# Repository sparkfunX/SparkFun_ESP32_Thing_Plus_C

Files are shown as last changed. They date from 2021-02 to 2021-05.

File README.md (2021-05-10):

SparkFun ESP32 Thing Plus C
========================================

SparkFun ESP32 Thing Plus C (https://www.sparkfun.com/products/18018)

[*SparkFun ESP32 Thing Plus C (SPX-18018)*](https://www.sparkfun.com/products/18018)

The [SparkFun ESP32 Thing Plus C](https://www.sparkfun.com/products/18018) is a comprehensive development platform for [Espressif's ESP32](https://espressif.com/en/products/hardware/esp32/overview). Like the 8266 and ESP32 Thing, the ESP32 Thing Plus is a **WiFi**-compatible microcontroller with support for both **Bluetooth Classic** (i.e. SPP) and **Bluetooth low-energy** (i.e. BLE, BT4.0, Bluetooth Smart), a Qwiic connector, and 21 I/O pins. Add to that a rich set of peripherals ranging from capacitive touch sensors, Hall sensors, SD card interface, Ethernet, high-speed SPIs, UARTs, I2S and I<sup>2</sup>C.

We took all the good from the original [ESP32 Thing Plus](https://www.sparkfun.com/products/15663) and sprinkled on some more! USB C provides up to 2A, upgraded 16MB flash ESP32 WROOM module, CH340 USB to serial IC, an onboard fuel gauge IC will make sure you know your battery levels, and an onboard addressable LED is perfect for as a multi-status LED. Oh, and the new taller reset and boot buttons are *so* much easier to push!

We added a dedicator regulator to the Qwiic connector to enable software power control of the Qwiic bus - great for low power logging! There's even a microSD connector on the back!

The ESP32 Thing plus integrates a rich set of peripherals, ranging from capacitive touch sensors, Hall sensors, SD card interface, Ethernet, high-speed SPI, UART, I2S and I2C. Thanks to the onboard ESP32 WROOM module, the SparkFun Thing Plus features 16MB of flash memory, 520kB of internal SRAM, an integrated 802.11 BGN WiFi transceiver and dual-mode Bluetooth capabilities, and a JST connector to plug in a LiPo battery.

For programming, select the 'ESP32 Dev Module'. This will get you direct pin to pin access to each of the WROOM's pins.

Repository Contents
-------------------

* **/Hardware** - Eagle design files (.brd, .sch)
* **/Firmware** - Example sketches demostrating extra peripherals

License Information
-------------------

This product is _**open source**_! 

Please review the LICENSE.md file for license information. 

If you have any questions or concerns on licensing, please contact technical support on our [SparkFun forums](https://forum.sparkfun.com/viewforum.php?f=152).

Distributed as-is; no warranty is given.

- Your friends at SparkFun.

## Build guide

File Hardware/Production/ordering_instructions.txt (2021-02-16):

panel size, 131x139mm
PCB thickness, 1.6mm
number of layers, 2
soldermask color, Black
silkscreen color, White
oz copper, 1oz
finish, HASL lead free
stencils, none
pcs per panel, 10
min trace width, 0.1270mm / 0.0050in
min drill size, 0.3048mm / 0.0120in

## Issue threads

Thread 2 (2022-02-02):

Add pullup to SD SDO

nseidle, 2022-02-02:
Intermittent issues with different SD cards fixed with a 100k pullup.

nseidle, 2022-02-02:
Reported issues with built-in ESP32 SD library. May behave differently with sdFat.

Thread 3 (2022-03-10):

QWIIC Twist and Quad Relay not recognized - Updated

jpecor, 2022-03-10:
I'm trying to use the Thing Plus C with a QWIIC Twist, and it does not recognize the device.  I have the Twist working with an RPi and Python library, so I know it functions.

I also tried the I2C scanner code from this repo, and the Twist is not seen on the bus.

Has the QWIIC interface been verified on this device?  Or is there something I should be doing differently?

jpecor, 2022-03-10:
I have the same issue with the QWIIC Quad Relay, so it's not just isolated to the Twist.

jpecor, 2022-03-10:
Yes, there is power to the Twist.  In fact, I ran the I2C scanner code, and it blinks the Twist LED, but there's no hit when it scans the addresses.

I haven't added other QWIIC boards to the chain to see if they are detected, yet.  I'll try that next.

jpecor, 2022-03-10:
Just tried with a QWIIC 9DoF IMU and PIR.  Same result.
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

PaulZC, 2022-03-10:
Hi Jason,

Which version of ESP32 do you have installed? And do you have the ESP32 Dev Module selected?

Qwiic / Wire is working fine for me...

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

Best wishes,
Paul

jpecor, 2022-03-10:
SHAZAM!!   I was not!  I was using the Adafruit ESP32 Feather based on the [instructions for the ESP32 Thing Plus.](https://learn.sparkfun.com/tutorials/esp32-thing-plus-hookup-guide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)

Changing to the ESP32 Dev Module seems to be the ticket.  Or, at least, I see the devices with the scanner code.

Now on to the intended application. If that works, I'll close this issue.

Thanks for the help!

jpecor, 2022-03-10:
That worked.  Thanks again!

jpecor, 2022-03-11:
I am reopening this issue because I've run into a new wrinkle.

Here's the situation:

- After switching the board to use the ESP32 Dev Module, the I2C Scanner sketch started working
- I switched back to my project setup, which is a Quad Relay and Twist, and it was working for those, as well.
- Then, we soldered header pins to the ESP32 C
- Post header attachment, I could no longer control the Twist/Relay - it doesn't see them there
- Additionally, if I have nothing connected to the QWIIC connector, the scanner tells me it's finding a device at 0x36

So, something changed post-header attachment.

Those through hole vias are *very* close to the ESP32 module CVs, and our concern was a possible solder bridge.  Everything looks very clean under the microscope.

Is it possible the proximity of the ESP32 module to the vias allowed some of the solder to flow under a CV and create an open on one of the module I/O?

I can still program the device, so it's not flat-out broken.  But the I2C bus is not working correctly.

Any thoughts?

Thanks!
Jason

PaulZC, 2022-03-11:
Hi Jason,

The device at 0x36 is the MAX17048 battery fuel gauge. That suggests the I2C bus is still working correctly.

Are you still connecting via the 4-Pin Qwiic connector? Maybe try connecting via the SCL/SDA header pins instead?

Best wishes,
Paul

jpecor, 2022-03-11:
Yes, I'm using the QWIIC connector.  I'll try the header pins next.

Thanks for the Intel on the battery gauge.  Good to know!

jpecor, 2022-03-11:
Direct connection to SDA/SCL works. Hmmm....

Thanks @PaulZC !

nseidle, 2022-03-14:
Sorry you're having so much trouble. Sounds like a bad Qwiic cable or bad connection. Continuity test the cable to see if it's bad. Also have a good look at the pins inside the Qwiic connector. It's rare but I've had an end pin bend sideways a few times.

Closing since it's not a hardware issue with the ESP32 Thing Plus C. Feel free to open more issues if you come across them.

Closed 2022-03-14.

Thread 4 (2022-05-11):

Digital write to pin 18

Rubeanie, 2022-05-11:
I am unable to write to digital pin 18 (sck)?
I am just trying as you would with any other pin, nothing fancy. Every other pin I'm using work.

PaulZC, 2022-05-11:
Hello Ruben (@Rubeanie ),

The Thing Plus C is intentionally connected up differently to our other ESP32 Thing Plus boards - to provide access to all of the I/O pins. For the Thing Plus C we recommend installing Espressif's ESP32 board package and then selecting the _ESP32 Dev Module_ as the board. Once you have done that, SCK is digital pin 18 - not 10.

Quick summary:
* Follow [Espressif's instructions ](https://docs.espressif.com/projects/arduino-esp32/en/latest/installing.html) to install the ESP32 board package
  * Add this line to your _Additional Board Manager URLs_ :
  * https://raw.githubusercontent.com/espressif/arduino-esp32/gh-pages/package_esp32_index.json
  * (If you have more than one additional URL, separate them with commas)
* Once you have the ESP32 boards installed, from the _Tools_ menu, select _Board_ \ _ESP32 Arduino_ \ _ESP32 Dev Module_
  * (Do not select any of the other Dev Modules, or any of the SparkFun ESP32 boards)

For more information on which pin is which, please refer to [the schematic](https://cdn.sparkfun.com/assets/b/5/1/0/9/SparkFun_ESP32_Thing_Plus_C.pdf):

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

Best wishes,
Paul

Rubeanie, 2022-05-12:
Sorry, that was a typo, I meant pin 18. I need to set it to 3v3 to run a stepper driver. All the other pins I'm using for it work aside from pin 18.

Rubeanie, 2022-05-13:
I set pin 18 to high, then checked all the pins with a multimeter. I found that pin 32 was high when trying to set pin 18. After finding this out, I tried setting pin 32 to high, and then pin 18 went high.
I don't think it's an issue with every board but for some reason, my pin 18 and 32 are swapped, it works fine now that I know this, it's just confusing.

PaulZC, 2022-05-13:
Hi Ruben (@Rubeanie ),

Wow. How bizarre! I _think_ the only way that can happen is if the variant pins_arduino.h has been changed, or if you have the wrong board selected? Please check one last time that you have the latest ESP32 boards (v2.0.3) installed and that you have the _**ESP32 Dev Module**_ selected.

I'm going to close this issue, but please re-open it if you need more help with this.

Very best wishes,
Paul

Closed 2022-05-13.

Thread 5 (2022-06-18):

SDIO functionality made impossible

idea--list, 2022-06-18:
Hooked up this board with an external uSD slot wired up for SDIO 4-bit mode as i was looking for high data rates.
On the ESP32 chip GPIO_2 and GPIO_7 have SD_DATA0 functionality.
On this board the RGB LED occupies GPIO_2. GPIO_7 is not broken out.
This is really unfortunate as this way we can not interface an SD card neither in SDIO 1-bit nor in SDIO 4-bit modes.

If the RGB LED would occupy either an SD_DATA1 or SD_DATA2 capable pin, we could use at least SDIO 1-bit mode (which needs SD_DATA0 and SD_DATA3)
Best would be however to keep all SDIO relevant pins broken out on the header.

PaulZC, 2022-06-21:
Hi Peter (@idea--list ),

This is a good suggestion - thank you. We will make note of this for future boards and revisions.

Forgive me for asking, but have you tried to use SDIO on this board? Yes, the RGB LED is connected to GPIO_2 but the LED is just an input. I suspect that SDIO may still work? OK, yes, the LED will be very confused and may show very random colors. But does it actually stop SDIO from working?

Many thanks,
Paul

idea--list, 2022-07-23:
@PaulZC
Was away for some time...

Just tried to test it once more.
Wrote some code in ESP-IDF to try different modes of SD-card connection.
This particular board uses the VSPI pins of the MCU to connect to the on-board uSD-slot, which is working as expected.
Using the HSPI pins i also connected an external uSD slot, which is also working fine in SPI mode. Yes, the RGB LED is occupying GPIO2 but the test point centrally from pin 4 seems to be the connection to the RGB LED. So while the external uSD slot is active, the RGB LED lights up in different colors.

However as soon as i switch to SDIO1 or SDIO4 modes i get this message in ESP-IDF:
E (6049) sdmmc_common: sdmmc_init_ocr: send_op_cond (1) returned 0x107
E (6050) vfs_fat_sdmmc: sdmmc_card_init failed (0x107).
[  6053][E][SD_MMC.cpp:138] begin(): Failed to initialize the card (0x107). Make sure SD card lines have pull-up resistors in place.

On my Wemos Lolin D32 and Adafruit Feather ESP32S3 boards even SDIO1 and SDIO4 modes work as expected, so i guess the RGB LED affects the pullups-check in ESP-IDF.

This issue became less relevant for me since the [Thing Plus Dual-Port Logging Shield](https://www.sparkfun.com/products/19217) has been released. Will absolutely need to buy some!

PaulZC, 2022-07-23:
Hi Peter (@idea--list ),

Many thanks for the feedback - we really appreciate it.

We have two new boards in the pipeline: a tweaked version of this Thing Plus C; and a new ESP32-WROOM-based board with microSD. The first won't support full SDIO as the changes would have been too drastic. For the second, I've designed in 4-bit SDIO from the start. It has the required pull-ups, plus isolation on the strapping pins so the pull-ups (which could be pull-downs if the microSD is deenergized!) won't interfere with the boot process.

Let me know how you get on with the dual-port shield. That was a fun design to work on! The first batch sold out really quickly. It should be back in stock soon.

Very best wishes,
Paul

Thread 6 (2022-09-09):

ESP32 GPIO peripheral interrupts issue - manifests as WiFi / power issue

idea--list, 2022-09-09:
Recently i added WiFi functionality to my project and ever since then i am facing reliability issues.

The program logic (written in ESP-IDF) does collect sensor data and records it to a uSD card using the on-board slot. I also slice up the files into 1 minute long units. Once the file of the following minute is created and recorded to, i wait 10 seconds before transferring the previous file over wifi. The wifi transaction takes only 2-8 seconds each minute. The code runs without any issues while powered from USB cable, no matter how many days the session takes. I am also using the auto light sleep feature of ESP-IDF to keep the consumption as low as possible.

However as soon as i power the board from a single 18650 battery, the program stops running between the 50th and 60th minute and on the server side i regularly find the last file smaller then on the SD card, meaning the ESP32 stopped working right during transmission of the previous file (actually also my router could be the issue but i guess if that was true, i would face the same issue even when the board is powered via USB).

First i thought it might be due to the 28-30 AWGish wires on the battery holder. So i rewired it with 20 AWG pure copper wires (10 cm long). I measure 0.2 ohms resistance on my batt cables, which i consider low enough, the battery has 3000 mAh capacity and  should be able to deliver 1.5A current to the battery pins via 20 AWG. Tried several different cells, with same result. I am still facing the same issue, which is also hard to debug as if i connect the USB cable the issue is gone...

Checked the board design, you have 12 mil power traces which should be able to deliver upto 1A on outer layers supposing 1oz copper (though, the AP2112 will max out at 600mA).
I found many people facing similar issue on different forums, essentially they tell the ESP32 is becoming a power hungry beast when WiFi is being used. Some tell we should use beefy capacitors to avoid brownouts, some tell one should try LiFePO batteries to bypass voltage regulators that might not be capable to deliver enough power when the ESP has a power surge.

My question is: what should i try to debug the issue on this board? Where should i try to solder a cap of which capacitance? Is the 3V3 pin the right one to try a LiFePO4 battery to power the MCU directly? Do you have any other idea which may help solving the issue?

PaulZC, 2022-09-11:
Hi Peter (@idea--list ),

We have a new version of the "Thing Plus C": https://www.sparkfun.com/products/20168 . It uses a newer 700mA 3.3V regulator, which may help. But I see that it does still use a 12mil power trace from the regulator to the ESP32 module.

My advice would be to try soldering a 100uF >=6V electrolytic capacitor between 3.3V and GND. That should help smooth out any power 'gulps' as the ESP32 transmits over WiFi.

If you have access to an oscilloscope, try probing on the 3.3V rail. Set the scope to trigger on a falling edge and set the trigger level to 3.2V. If you see the scope trigger, you know the voltage level is falling to a point where the regulator stops regulating. If it is a dual-channel scope, try using the second channel to monitor the battery voltage. Do you see the battery voltage dip at the same instant? What voltage does it dip to?

I hope this helps,
Paul

idea--list, 2022-09-17:
Hello Paul (@PaulZC ),

Sorry for the delayed reply i have digged myself into my rabbit hole.
Thanks for the suggestions, i do not have an oscilloscope but i programmed another ESP32 to make voltage readings.
Could not notice anything special yet, but for sure it is not as good as an oscilloscope would be.

ESP-IDF has a ton of setting options in menukonfig and it seems after increasing different stack sizes, WiFi has become more stable... i am still crossing my fingers but i learned to became cautious with WiFi on the ESP32 in general. Will need to run several long term tests in the following 1-2 weeks as it always takes a while until the problem occurs.

I seriously think you guys consider my whishes. I mean i was daydreaming about good SD slots and a DA16200 based feather and now you have both on offer ;-)

idea--list, 2022-10-05:
Took long to sort it out, but i finally managed to solve it. 😄
I was using edge type interrupts with my sensor and the on-board button. It turns out the ESP32 has a HW issue: the chip just stops triggering interrupts after a while (listed as error 3.14 in the [errata](https://www.espressif.com/sites/default/files/documentation/eco_and_workarounds_for_bugs_in_esp32_en.pdf)).

My sensor has an onboard FIFO interrupt signal is issued when it is 50% full so that the MCU will readout the data. This readout also detects if the FIFO has been overflown or not. If so the sensor stops issuing further interrupt signals until its FIFO gets resetted. Exactly that is what happened because of the above error.

Until recently i did not pin my tasks to specific cores and was keep facing the same issue. After a ton trial&error it turns out that the workaround needs a core that can react instantly. However when the scheduler automatically manages which core will execute a call, then once every 1-3 hours the workaround can not be executed instantly and the same issue manifests as before applying the fix. It just takes even longer to sort it out...a

So long story short: WiFi and FTP logic can coexist just fine pinned to core 0, anything else needs to be on core 1 and we also need to be careful with task priorities to avoid priority inversions which would again reintroduce the same issue. Revised code seems to finish 6 hour long tests reliably without any capacitors. It was not a power supply issue as i supposed at the beginning.

PaulZC, 2022-10-05:
Hi Peter (@idea--list ),

Wow. Great detective work!

Many thanks for the update. I'm going to pin this issue as other people will find it useful.

Very best wishes,
Paul

Closed 2022-10-05.

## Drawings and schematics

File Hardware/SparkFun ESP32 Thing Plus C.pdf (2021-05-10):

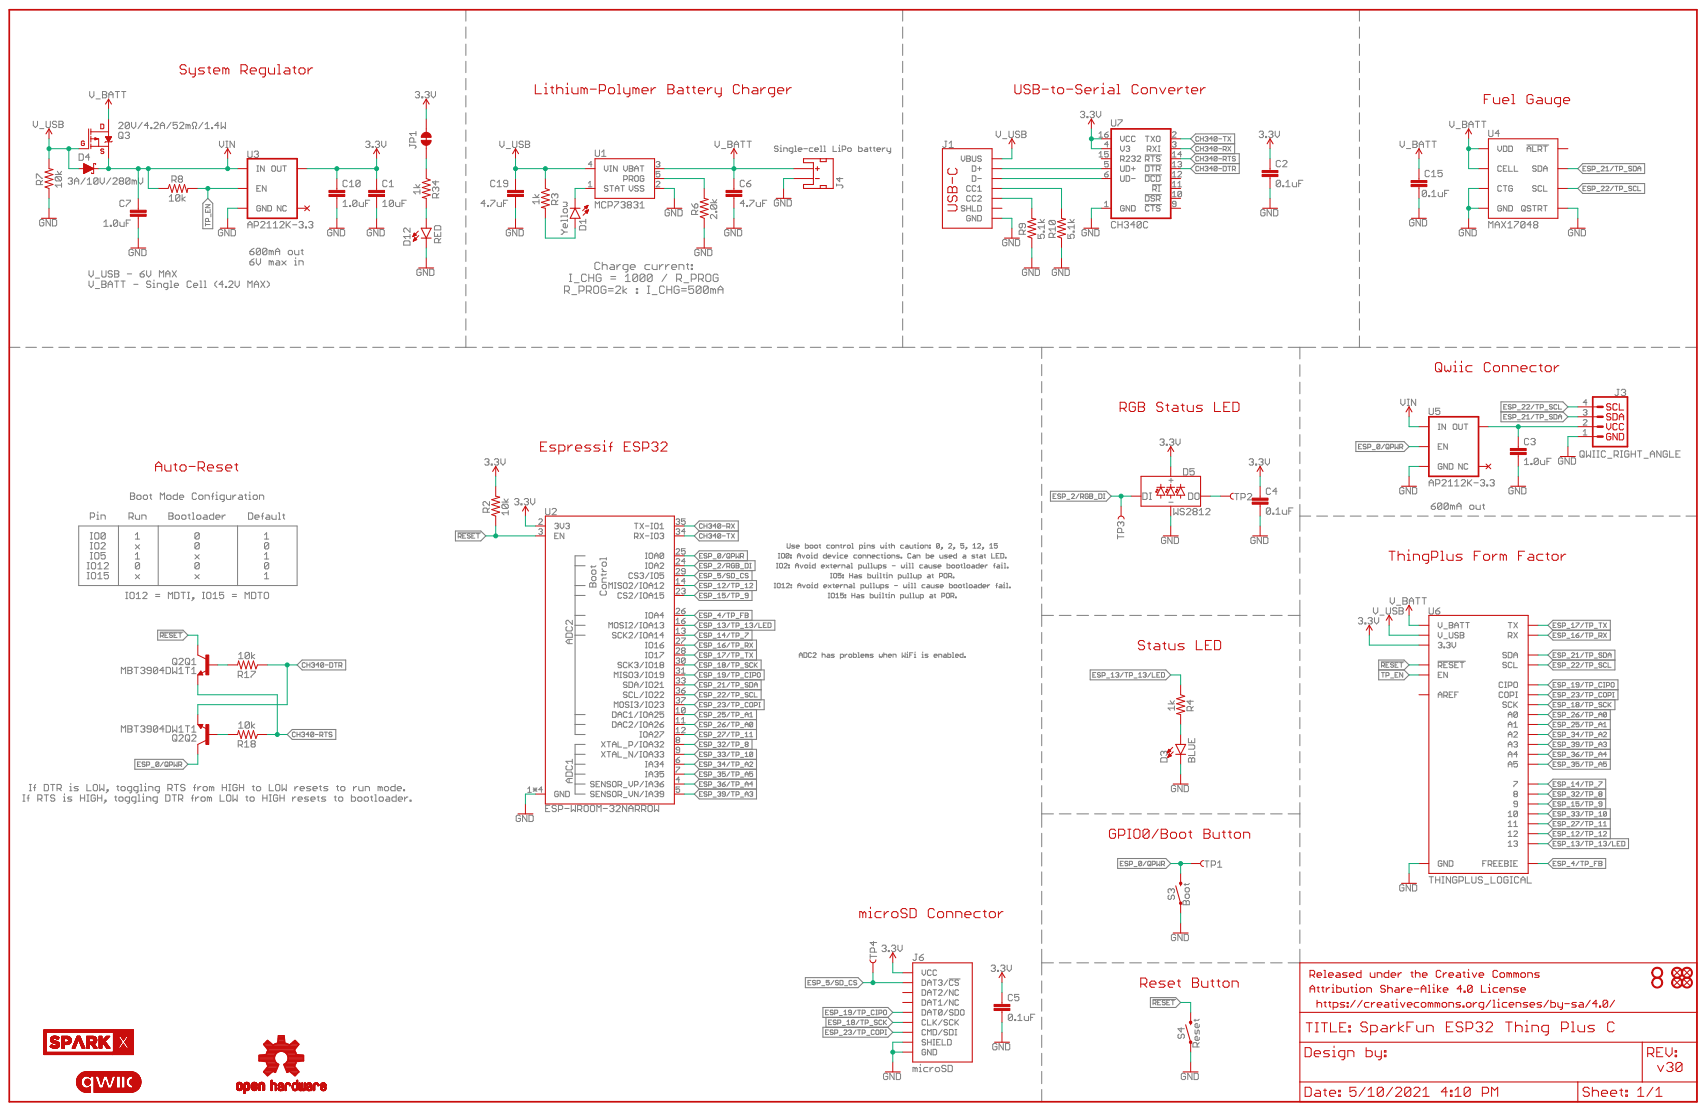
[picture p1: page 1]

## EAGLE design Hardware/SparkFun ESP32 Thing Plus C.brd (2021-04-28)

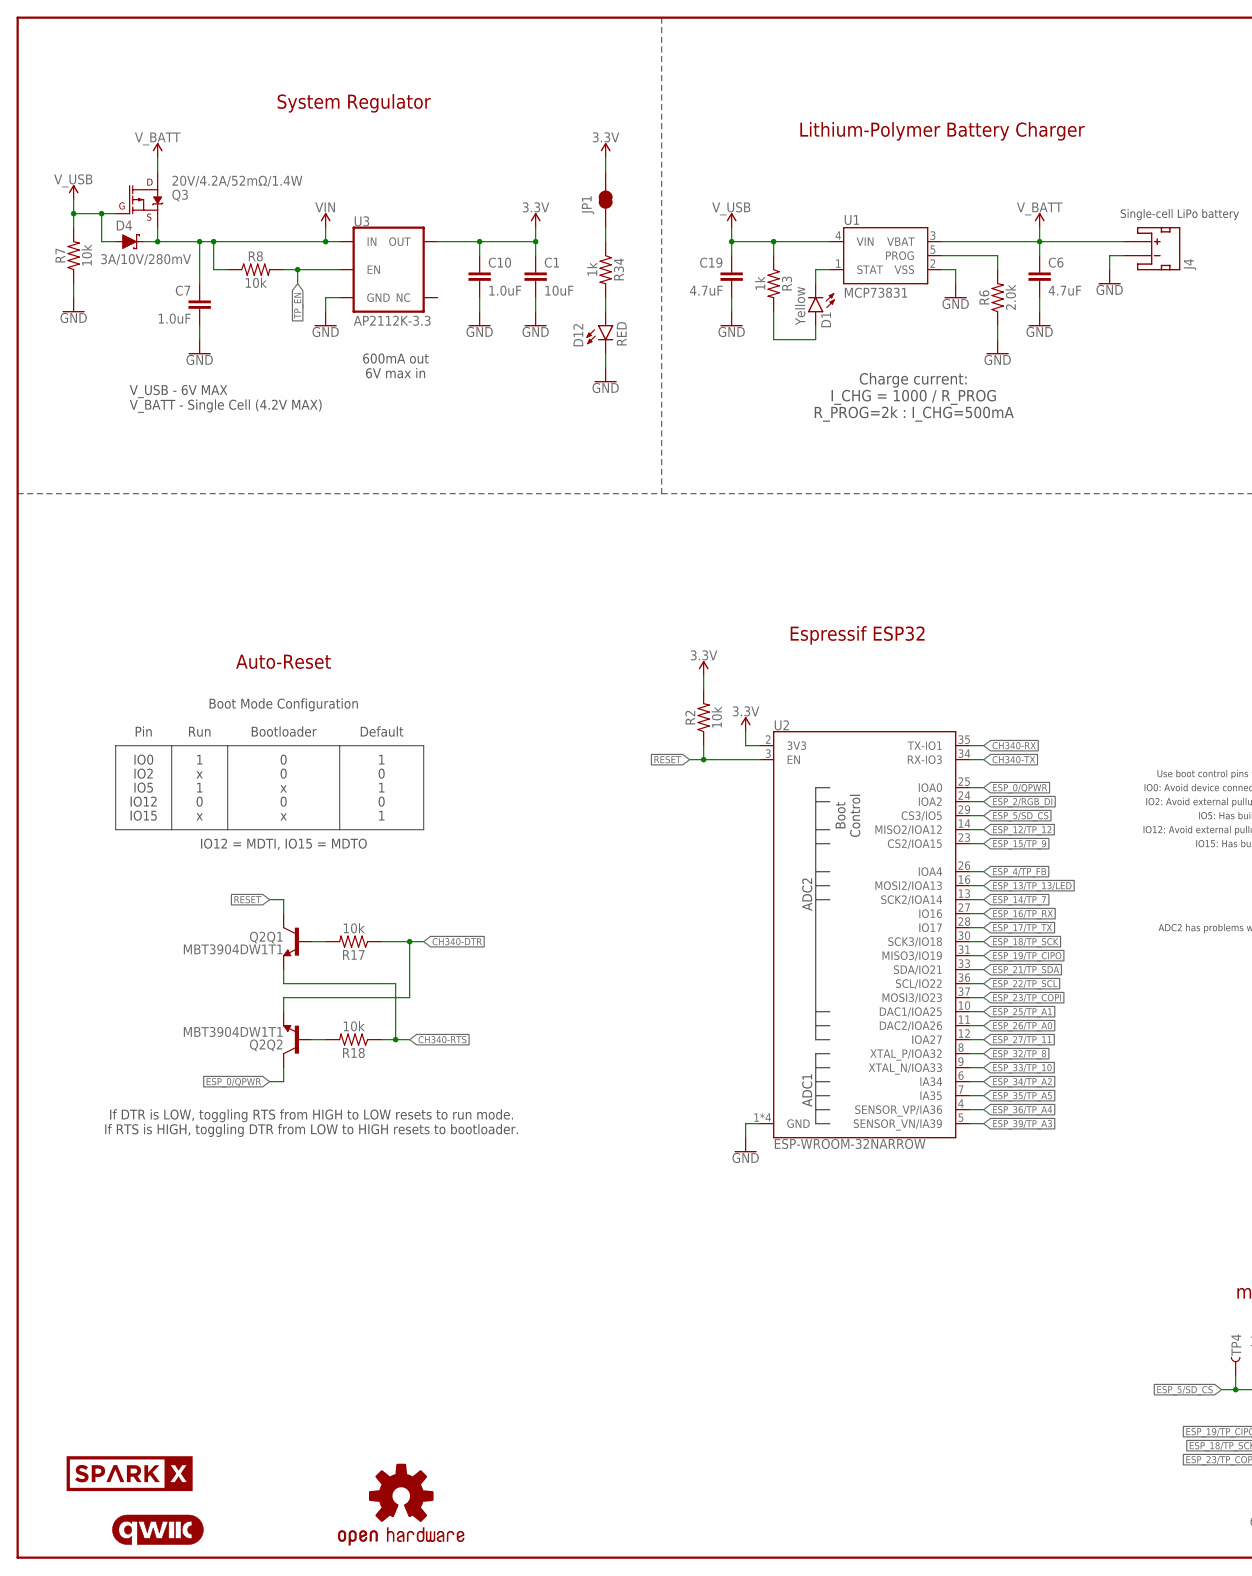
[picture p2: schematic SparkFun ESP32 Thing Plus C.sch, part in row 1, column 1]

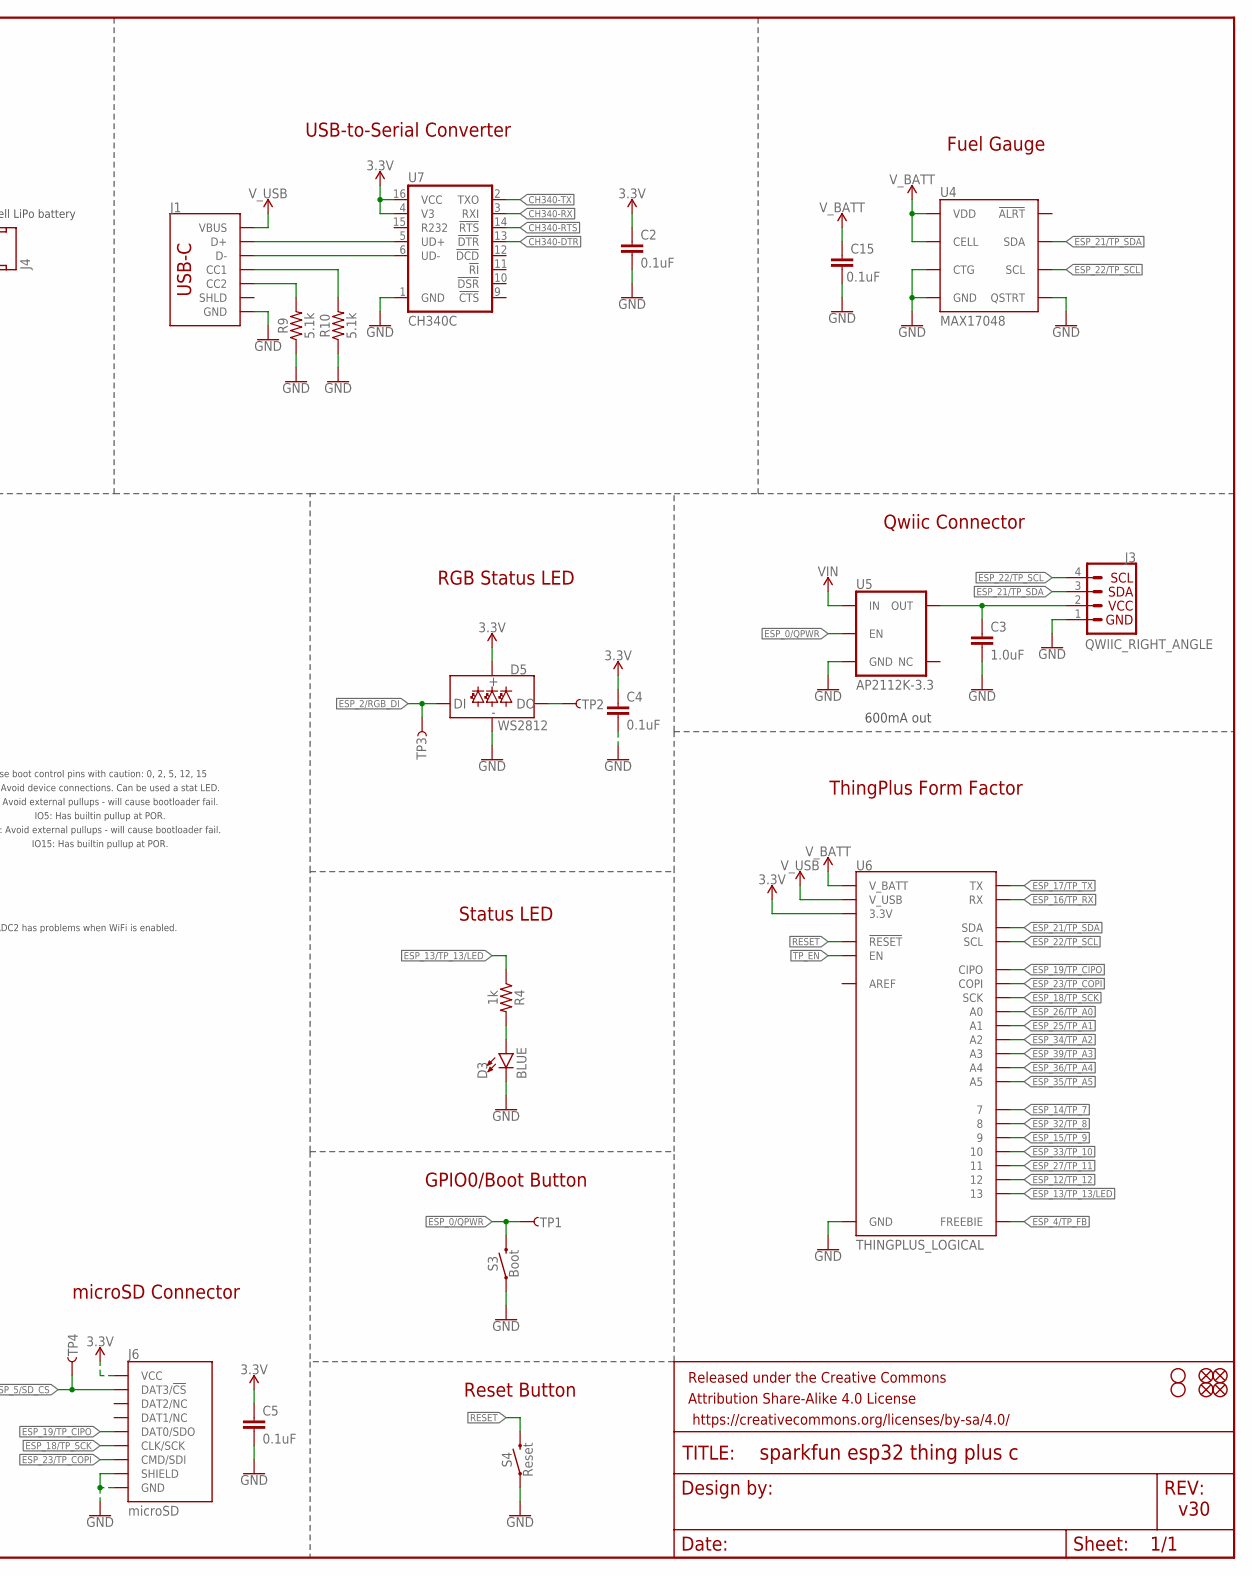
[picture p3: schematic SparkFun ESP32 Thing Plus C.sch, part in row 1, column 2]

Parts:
C1: 10uF; 0402-TIGHT
C2, C4, C5, C15: 0.1uF; 0402-TIGHT
C3, C7, C10: 1.0uF; 0402-TIGHT
C6: 4.7uF; 0402-TIGHT
C19: 4.7uF; 0603
D1: Yellow; LED-0603
D3: BLUE; LED-0603
D4: 3A/10V/280mV; SOD-323
D5: WS2812; WS2812-2020
D12: RED; LED-0603
FD1, FD2, FD3, FD4: FIDUCIALUFIDUCIAL; FIDUCIAL-MICRO
FRAME1: FRAME-LEDGER; CREATIVE_COMMONS
H1, H2: STAND-OFFTIGHT; STAND-OFF-TIGHT
J1: USB_C_2-LAYER_PADS; USB-C-16P-2LAYER-PADS
J3: QWIIC_RIGHT_ANGLE; JST04_1MM_RA
J4: JST_2MM_MALE; JST-2-SMD
J6: microSD; MICRO-SD-SOCKET
JP1: JUMPER-SMT_2_NC_TRACE_SILK; SMT-JUMPER_2_NC_TRACE_SILK
LOGO2: OSHW-LOGOMINI; OSHW-LOGO-MINI
LOGO4: QWIIC_LOGO_4MM; QWIIC_4MM
Q2: MBT3904DW1T1; SC70-6
Q3: 20V/4.2A/52mΩ/1.4W; SOT23-3
R2, R7, R8, R17, R18: 10k; 0402-TIGHT
R3, R4, R34: 1k; 0402-TIGHT
R6: 2.0k; 0603
R9, R10: 5.1k; 0402-TIGHT
S3: Boot; TACTILE_SWITCH_SMD_4.6X2.8MM
S4: Reset; TACTILE_SWITCH_SMD_4.6X2.8MM
TP1, TP2, TP3, TP4: TEST-POINT3X5; PAD.03X.05
U1: MCP73831; SOT23-5
U2: ESP-WROOM-32NARROW; ESP-WROOM-32-NARROW
U3, U5: AP2112K-3.3; SOT23-5
U4: MAX17048; DFN-8
U6: THINGPLUS_LOGICAL; THINGPLUS_FOOTPRINT
U7: CH340C; SO016
U$1: SPARKX-LOGO4; SPARKX-MEDIUM

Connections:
3.3V: C1.1, C2.1, C4.1, C5.1, C10.1, D5.VCC, J6.VCC, JP1.2, R2.2, U2.2 (3V3), U3.5 (OUT), U6.3V3 (3.3V), U7.4 (V3), U7.16 (VCC)
!RESET!: Q2.3 (C), R2.1, S4.3 (2), S4.4 (2), U2.3 (EN), U6.RST (!RESET)
CH340-DTR: Q2.1 (E), R17.1, U7.13 (!DTR)
CH340-RTS: Q2.4 (E), R18.1, U7.14 (!RTS)
CH340-RX: U2.35 (TX-IO1), U7.3 (RXI)
CH340-TX: U2.34 (RX-IO3), U7.2 (TXO)
CHG: D1.C, U1.1 (STAT)
CHG_LED: D1.A, R3.2
D+: J1.A6 (D+), J1.B6 (D+), U7.5 (UD+)
D-: J1.A7 (D-), J1.B7 (D-), U7.6 (UD-)
DTR-10K: Q2.5 (B), R17.2
ESP_0/QPWR: Q2.6 (C), S3.3 (2), S3.4 (2), TP1.P$1, U2.25 (IOA0), U5.3 (EN)
ESP_2/RGB_DI: D5.DI, TP3.P$1, U2.24 (IOA2)
ESP_4/TP_FB: U2.26 (IOA4), U6.FREEBIE
ESP_5/SD_CS: J6.CS/DAT3 (DAT3/!CS!), TP4.P$1, U2.29 (CS3/IO5)
ESP_12/TP_12: U2.14 (MISO2/IOA12), U6.12
ESP_13/TP_13/LED: R4.1, U2.16 (MOSI2/IOA13), U6.13
ESP_14/TP_7: U2.13 (SCK2/IOA14), U6.7
ESP_15/TP_9: U2.23 (CS2/IOA15), U6.9
ESP_16/TP_RX: U2.27 (IO16), U6.RX
ESP_17/TP_TX: U2.28 (IO17), U6.TX
ESP_18/TP_SCK: J6.SCLK (CLK/SCK), U2.30 (SCK3/IO18), U6.SCK
ESP_19/TP_CIPO: J6.DO/DAT0 (DAT0/SDO), U2.31 (MISO3/IO19), U6.CIPO
ESP_21/TP_SDA: J3.3, U2.33 (SDA/IO21), U4.8 (SDA), U6.SDA
ESP_22/TP_SCL: J3.4, U2.36 (SCL/IO22), U4.7 (SCL), U6.SCL
ESP_23/TP_COPI: J6.DI/CMD (CMD/SDI), U2.37 (MOSI3/IO23), U6.COPI
ESP_25/TP_A1: U2.10 (DAC1/IOA25), U6.A1
ESP_26/TP_A0: U2.11 (DAC2/IOA26), U6.A0
ESP_27/TP_11: U2.12 (IOA27), U6.11
ESP_32/TP_8: U2.8 (XTAL_P/IOA32), U6.8
ESP_33/TP_10: U2.9 (XTAL_N/IOA33), U6.10
ESP_34/TP_A2: U2.6 (IA34), U6.A2
ESP_35/TP_A5: U2.7 (IA35), U6.A5
ESP_36/TP_A4: U2.4 (SENSOR_VP/IA36), U6.A4
ESP_39/TP_A3: U2.5 (SENSOR_VN/IA39), U6.A3
GND: C1.2, C2.2, C3.2, C4.2, C5.2, C6.2, C7.2, C10.2, C15.2, C19.2, D3.C, D5.GND, D12.C, J1.GND, J1.GND2 (GND), J3.1, J4.1 (-), J6.CD1 (SHIELD), J6.GND, J6.GND1 (GND), J6.GND3 (GND), R6.1, R7.1, R9.1, R10.1, S3.1, S3.2 (1), S4.1, S4.2 (1), U1.2 (VSS), U2.1 (GND), U2.15 (GND), U2.38 (GND), U2.GND, U3.2 (GND), U4.1 (CTG), U4.4 (GND), U4.6 (QSTRT), U4.9 (GND), U5.2 (GND), U6.GND, U7.1 (GND)
unnamed: JP1.1, R34.1
unnamed: D3.A, R4.2
unnamed: D5.DO, TP2.P$1
unnamed: J1.B5 (CC2), R9.2
unnamed: J1.A5 (CC1), R10.2
unnamed: R6.2, U1.5 (PROG)
unnamed: D12.A, R34.2
QWIIC_PWR: C3.1, J3.2, U5.5 (OUT)
RTS-10K: Q2.2 (B), R18.2
TP_EN: R8.2, U3.3 (EN), U6.EN
VIN: C7.1, D4.C, Q3.2 (S), R8.1, U3.1 (IN), U5.1 (IN)
V_BATT: C6.1, C15.1, J4.2 (+), Q3.3 (D), U1.3 (VBAT), U4.2 (CELL), U4.3 (VDD), U6.V_BATT
V_USB: C19.1, D4.A, J1.VBUS1 (VBUS), J1.VBUS2 (VBUS), Q3.1 (G), R3.1, R7.2, U1.4 (VIN), U6.V_USB

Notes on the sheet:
USB-to-Serial Converter
Single-cell LiPo battery
Charge current: I_CHG = 1000 / R_PROG R_PROG=2k : I_CHG=500mA
System Regulator
Lithium-Polymer Battery Charger
600mA out 6V max in
Auto-Reset
Espressif ESP32
Reset Button
ThingPlus Form Factor
v30
If DTR is LOW, toggling RTS from HIGH to LOW resets to run mode. If RTS is HIGH, toggling DTR from LOW to HIGH resets to bootloader.
Qwiic Connector
Status LED
GPIO0/Boot Button
V_USB - 6V MAX V_BATT - Single Cell (4.2V MAX)
Pin
IO0
IO2
IO12
IO15
IO5
Run
Bootloader
Default
IO12 = MDTI, IO15 = MDTO
Boot Mode Configuration
IO0: Avoid device connections. Can be used a stat LED.
ADC2 has problems when WiFi is enabled.
IO12: Avoid external pullups - will cause bootloader fail.
Use boot control pins with caution: 0, 2, 5, 12, 15
IO2: Avoid external pullups - will cause bootloader fail.
Fuel Gauge
600mA out
RGB Status LED
microSD Connector
IO15: Has builtin pullup at POR.
IO5: Has builtin pullup at POR.

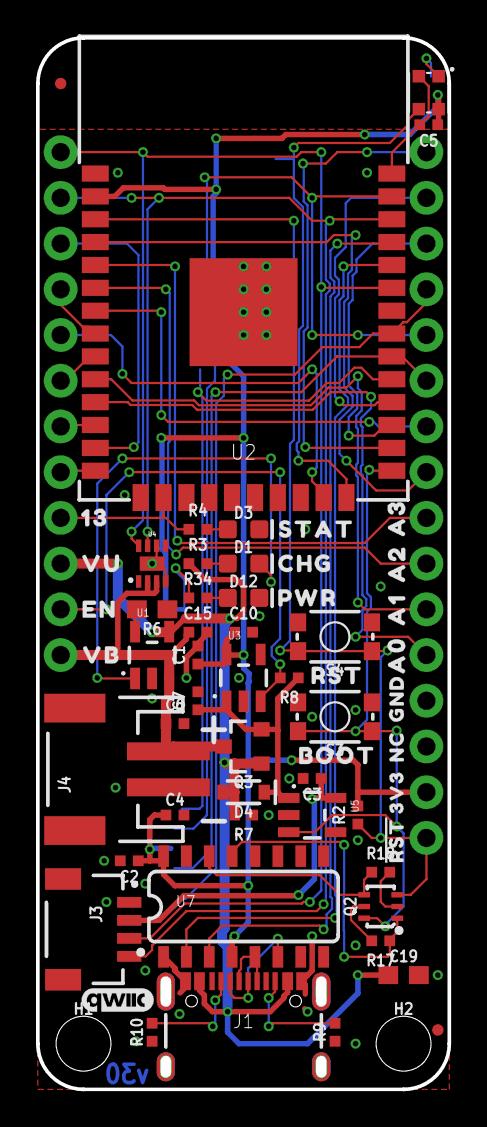
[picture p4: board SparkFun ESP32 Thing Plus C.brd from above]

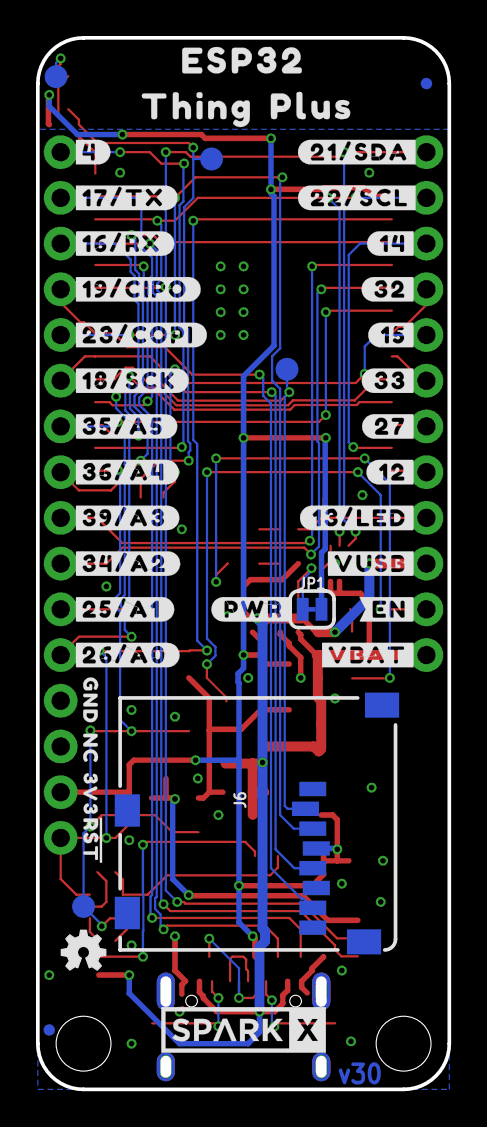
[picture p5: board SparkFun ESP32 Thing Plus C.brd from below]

Board: 2 copper layers, 22.9 x 58.4 mm, 106 parts (42 on the bottom side), 49 nets.

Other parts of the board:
U$23, U$108: 3V30
U$24: CHG1
U$25: PWR2
U$26: STAT0
U$56, U$75: GND1
U$57: #4#0
U$59: ORDERING_INSTRUCTIONS
U$62: #23#COPI#0
U$68: A03
U$69: A12
U$70: A21
U$71: A30
U$72: #17#TX#0
U$73: VB1
U$74: EN3
U$76: VU0
U$77: 130
U$78: BOOT0
U$79, U$109: #RST#0
U$80: RST0
U$81: #16#RX#0
U$82: #19#CIPO#0
U$83: #18#SCK#0
U$84: #35#A5#0
U$85: #36#A4#0
U$86: #25#A1#2
U$87: #26#A0#3
U$88: #34#A2#1
U$89: #39#A3#0
U$90: #12#4
U$91: #14#9
U$92: #15#7
U$93: #27#5
U$94: #32#8
U$95: #33#6
U$96: #EN#1
U$97: #VBAT#0
U$98: #VUSB#2
U$99: #13#LED#0
U$100: #21#SDA#1
U$101: #22#SCL#0
U$102: #PWR#0
U$103: ESP320
U$104: THING1
U$105: PLUS2
U$106, U$107: NC0

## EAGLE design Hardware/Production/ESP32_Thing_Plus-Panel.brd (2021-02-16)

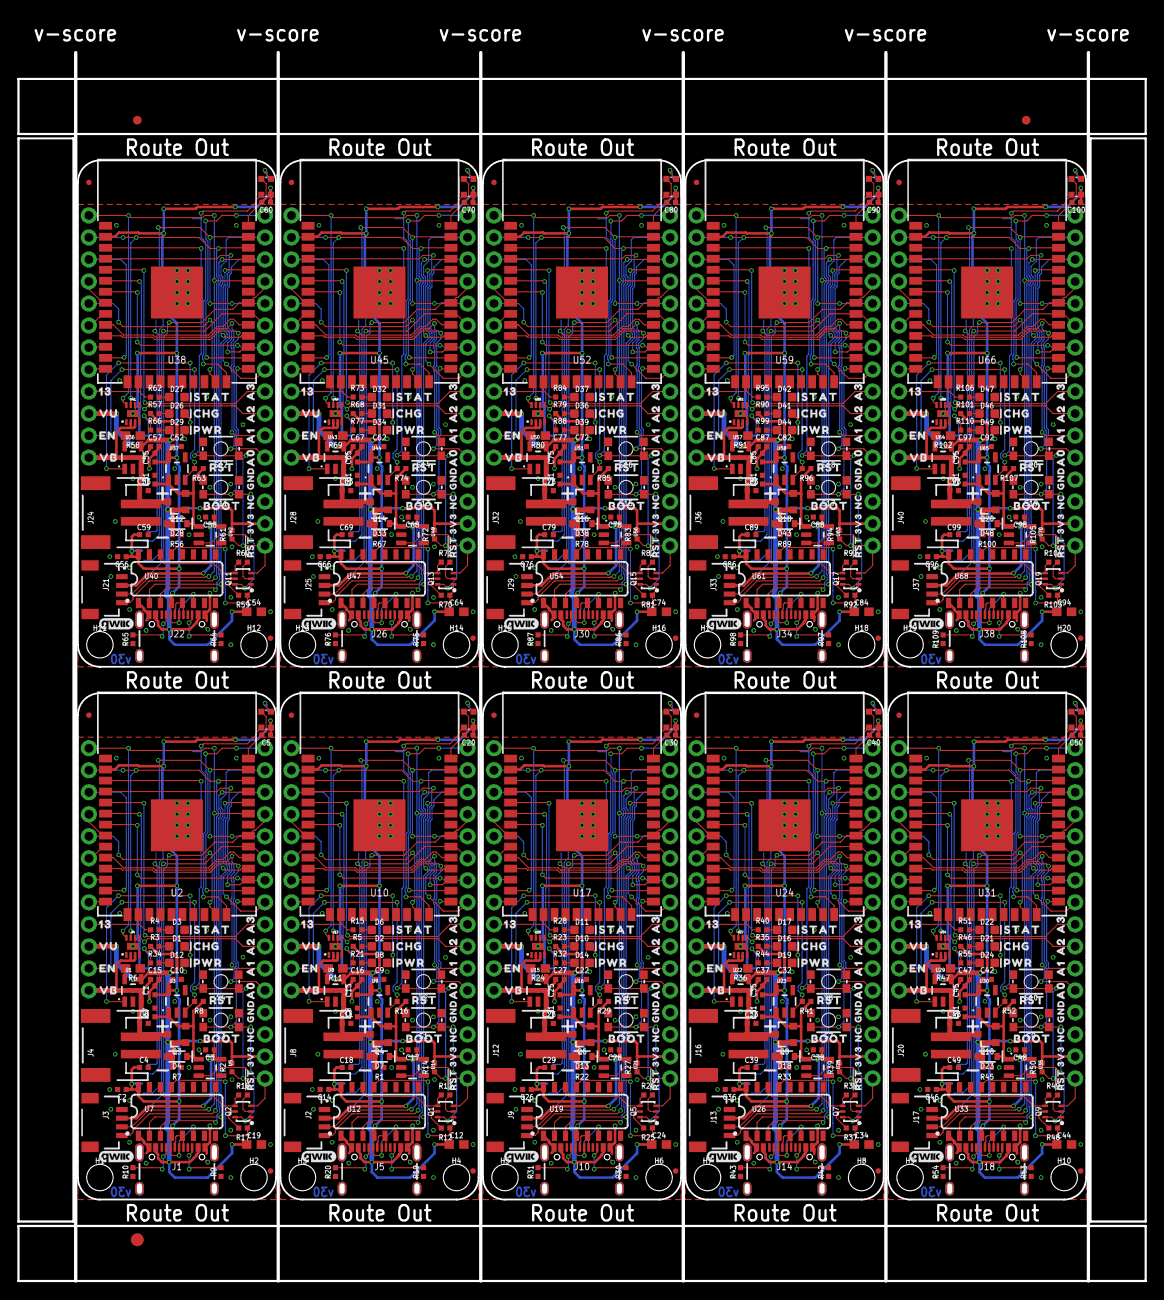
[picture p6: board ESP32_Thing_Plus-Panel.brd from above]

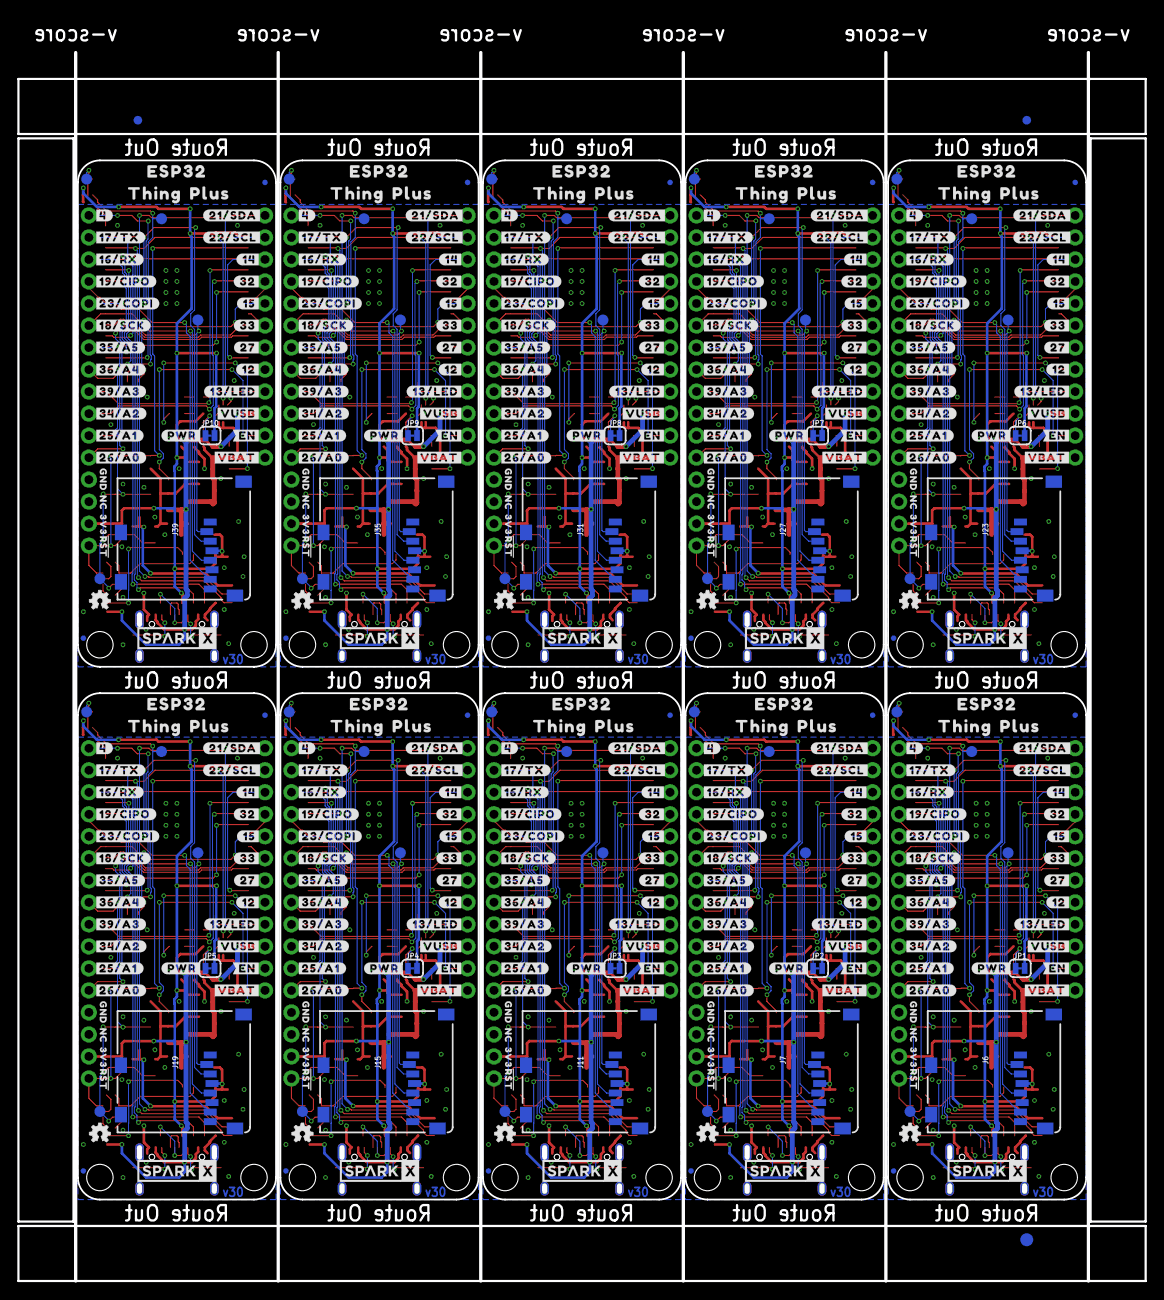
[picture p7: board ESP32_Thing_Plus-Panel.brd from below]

Board: 2 copper layers, 130.0 x 141.7 mm, 1046 parts (423 on the bottom side), 490 nets.

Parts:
C1, C13, C25, C35, C45, C55, C65, C75, C85, C95: 10uF; 0402-TIGHT
C2, C4, C5, C14, C15, C16, C18, C20, C26, C27, C29, C30, C36, C37, C39, C40, C46, C47, C49, C50, C56, C57, C59, C60, C66, C67, C69, C70, C76, C77, C79, C80, C86, C87, C89, C90, C96, C97, C99, C100: 0.1uF; 0402-TIGHT
C3, C7, C8, C9, C10, C17, C21, C22, C28, C31, C32, C38, C41, C42, C48, C51, C52, C58, C61, C62, C68, C71, C72, C78, C81, C82, C88, C91, C92, C98: 1.0uF; 0402-TIGHT
C6, C11, C23, C33, C43, C53, C63, C73, C83, C93: 4.7uF; 0402-TIGHT
C12, C19, C24, C34, C44, C54, C64, C74, C84, C94: 4.7uF; 0603
D1, D2, D10, D16, D21, D26, D31, D36, D41, D46: Yellow; LED-0603
D3, D6, D11, D17, D22, D27, D32, D37, D42, D47: BLUE; LED-0603
D4, D7, D13, D18, D23, D28, D33, D38, D43, D48: 3A/10V/280mV; SOD-323
D5, D9, D15, D20, D25, D30, D35, D40, D45, D50: WS2812; WS2812-2020
D8, D12, D14, D19, D24, D29, D34, D39, D44, D49: RED; LED-0603
E$1, E$2, E$3, E$4: FIDUCIAL-1X2
E$5, E$6: FIDUCIAL-1.5X3
FD1, FD2, FD3, FD4, FD5, FD6, FD7, FD8, FD9, FD10, FD11, FD12, FD13, FD14, FD15, FD16, FD17, FD18, FD19, FD20, FD21, FD22, FD23, FD24, FD25, FD26, FD27, FD28, FD29, FD30, FD31, FD32, FD33, FD34, FD35, FD36, FD37, FD38, FD39, FD40: FIDUCIALUFIDUCIAL; FIDUCIAL-MICRO
H1, H2, H3, H4, H5, H6, H7, H8, H9, H10, H11, H12, H13, H14, H15, H16, H17, H18, H19, H20: STAND-OFFTIGHT; STAND-OFF-TIGHT
J1, J5, J10, J14, J18, J22, J26, J30, J34, J38: USB-C-16P-2LAYER-PADS
J2, J3, J9, J13, J17, J21, J25, J29, J33, J37: QWIIC_RIGHT_ANGLE; JST04_1MM_RA
J4, J8, J12, J16, J20, J24, J28, J32, J36, J40: JST-2-SMD
J6, J7, J11, J15, J19, J23, J27, J31, J35, J39: microSD; MICRO-SD-SOCKET
JP1, JP2, JP3, JP4, JP5, JP6, JP7, JP8, JP9, JP10: SMT-JUMPER_2_NC_TRACE_SILK
LOGO1, LOGO2, LOGO5, LOGO7, LOGO9, LOGO11, LOGO13, LOGO15, LOGO17, LOGO19: OSHW-LOGOMINI; OSHW-LOGO-MINI
LOGO3, LOGO4, LOGO6, LOGO8, LOGO10, LOGO12, LOGO14, LOGO16, LOGO18, LOGO20: QWIIC_LOGO_4MM; QWIIC_4MM
Q1, Q2, Q5, Q7, Q9, Q11, Q13, Q15, Q17, Q19: MBT3904DW1T1; SC70-6
Q3, Q4, Q6, Q8, Q10, Q12, Q14, Q16, Q18, Q20: 20V/4.2A/52mΩ/1.4W; SOT23-3
R1, R2, R7, R8, R12, R13, R14, R16, R17, R18, R22, R25, R26, R27, R29, R33, R37, R38, R39, R41, R45, R48, R49, R50, R52, R56, R59, R60, R61, R63, R67, R70, R71, R72, R74, R78, R81, R82, R83, R85, R89, R92, R93, R94, R96, R100, R103, R104, R105, R107: 10k; 0402-TIGHT
R3, R4, R5, R15, R21, R23, R28, R32, R34, R35, R40, R44, R46, R51, R55, R57, R62, R66, R68, R73, R77, R79, R84, R88, R90, R95, R99, R101, R106, R110: 1k; 0402-TIGHT
R6, R11, R24, R36, R47, R58, R69, R80, R91, R102: 2.0k; 0603
R9, R10, R19, R20, R30, R31, R42, R43, R53, R54, R64, R65, R75, R76, R86, R87, R97, R98, R108, R109: 5.1k; 0402-TIGHT
S1, S3, S5, S7, S9, S11, S13, S15, S17, S19: Boot; TACTILE_SWITCH_SMD_4.6X2.8MM
S2, S4, S6, S8, S10, S12, S14, S16, S18, S20: Reset; TACTILE_SWITCH_SMD_4.6X2.8MM
TP1, TP2, TP3, TP4, TP5, TP6, TP7, TP8, TP9, TP10, TP11, TP12, TP13, TP14, TP15, TP16, TP17, TP18, TP19, TP20, TP21, TP22, TP23, TP24, TP25, TP26, TP27, TP28, TP29, TP30, TP31, TP32, TP33, TP34, TP35, TP36, TP37, TP38, TP39, TP40: PAD.03X.05
U1, U8, U15, U22, U29, U36, U43, U50, U57, U64: MCP73831; SOT23-5
U2, U10, U17, U24, U31, U38, U45, U52, U59, U66: ESP-WROOM-32NARROW; ESP-WROOM-32-NARROW
U3, U5, U9, U14, U16, U21, U23, U28, U30, U35, U37, U42, U44, U49, U51, U56, U58, U63, U65, U70: AP2112K-3.3; SOT23-5
U4, U13, U20, U27, U34, U41, U48, U55, U62, U69: MAX17048; DFN-8
U6, U11, U18, U25, U32, U39, U46, U53, U60, U67: THINGPLUS_LOGICAL; THINGPLUS_FOOTPRINT
U7, U12, U19, U26, U33, U40, U47, U54, U61, U68: CH340C; SO016
U$1, U$55, U$150, U$200, U$250, U$300, U$350, U$400, U$450, U$500: SPARKX-LOGO4; SPARKX-MEDIUM
U$2, U$24, U$58, U$151, U$201, U$251, U$301, U$351, U$401, U$451: CHG1
U$3, U$25, U$59, U$152, U$202, U$252, U$302, U$352, U$402, U$452: PWR2
U$4, U$26, U$60, U$153, U$203, U$253, U$303, U$353, U$403, U$453: STAT0
U$5, U$61, U$68, U$154, U$204, U$254, U$304, U$354, U$404, U$454: A03
U$6, U$63, U$69, U$155, U$205, U$255, U$305, U$355, U$405, U$455: A12
U$7, U$64, U$70, U$156, U$206, U$256, U$306, U$356, U$406, U$456: A21
U$8, U$65, U$71, U$157, U$207, U$257, U$307, U$357, U$407, U$457: A30
U$9, U$66, U$74, U$158, U$208, U$258, U$308, U$358, U$408, U$458: EN3
U$10, U$67, U$77, U$159, U$209, U$259, U$309, U$359, U$409, U$459: 130
U$11, U$78, U$110, U$160, U$210, U$260, U$310, U$360, U$410, U$460: BOOT0
U$12, U$50, U$79, U$109, U$111, U$145, U$161, U$195, U$211, U$245, U$261, U$295, U$311, U$345, U$361, U$395, U$411, U$445, U$461, U$495: #RST#0
U$13, U$80, U$112, U$162, U$212, U$262, U$312, U$362, U$412, U$462: RST0
U$14, U$73, U$113, U$163, U$213, U$263, U$313, U$363, U$413, U$463: VB1
U$15, U$76, U$114, U$164, U$214, U$264, U$314, U$364, U$414, U$464: VU0
U$16, U$23, U$49, U$108, U$115, U$144, U$165, U$194, U$215, U$244, U$265, U$294, U$315, U$344, U$365, U$394, U$415, U$444, U$465, U$494: 3V30
U$17, U$57, U$116, U$166, U$216, U$266, U$316, U$366, U$416, U$466: #4#0
U$18, U$62, U$117, U$167, U$217, U$267, U$317, U$367, U$417, U$467: #23#COPI#0
U$19, U$72, U$118, U$168, U$218, U$268, U$318, U$368, U$418, U$468: #17#TX#0
U$20, U$81, U$119, U$169, U$219, U$269, U$319, U$369, U$419, U$469: #16#RX#0
U$21, U$82, U$120, U$170, U$220, U$270, U$320, U$370, U$420, U$470: #19#CIPO#0
U$22, U$83, U$121, U$171, U$221, U$271, U$321, U$371, U$421, U$471: #18#SCK#0
U$27, U$84, U$122, U$172, U$222, U$272, U$322, U$372, U$422, U$472: #35#A5#0
U$28, U$85, U$123, U$173, U$223, U$273, U$323, U$373, U$423, U$473: #36#A4#0
U$29, U$86, U$124, U$174, U$224, U$274, U$324, U$374, U$424, U$474: #25#A1#2
U$30, U$87, U$125, U$175, U$225, U$275, U$325, U$375, U$425, U$475: #26#A0#3
U$31, U$88, U$126, U$176, U$226, U$276, U$326, U$376, U$426, U$476: #34#A2#1
U$32, U$89, U$127, U$177, U$227, U$277, U$327, U$377, U$427, U$477: #39#A3#0
U$33, U$90, U$128, U$178, U$228, U$278, U$328, U$378, U$428, U$478: #12#4
U$34, U$91, U$129, U$179, U$229, U$279, U$329, U$379, U$429, U$479: #14#9
U$35, U$92, U$130, U$180, U$230, U$280, U$330, U$380, U$430, U$480: #15#7
U$36, U$93, U$131, U$181, U$231, U$281, U$331, U$381, U$431, U$481: #27#5
U$37, U$94, U$132, U$182, U$232, U$282, U$332, U$382, U$432, U$482: #32#8
U$38, U$95, U$133, U$183, U$233, U$283, U$333, U$383, U$433, U$483: #33#6
U$39, U$96, U$134, U$184, U$234, U$284, U$334, U$384, U$434, U$484: #EN#1
U$40, U$97, U$135, U$185, U$235, U$285, U$335, U$385, U$435, U$485: #VBAT#0
U$41, U$98, U$136, U$186, U$236, U$286, U$336, U$386, U$436, U$486: #VUSB#2
U$42, U$99, U$137, U$187, U$237, U$287, U$337, U$387, U$437, U$487: #13#LED#0
U$43, U$100, U$138, U$188, U$238, U$288, U$338, U$388, U$438, U$488: #21#SDA#1
U$44, U$101, U$139, U$189, U$239, U$289, U$339, U$389, U$439, U$489: #22#SCL#0
U$45, U$102, U$140, U$190, U$240, U$290, U$340, U$390, U$440, U$490: #PWR#0
U$46, U$103, U$141, U$191, U$241, U$291, U$341, U$391, U$441, U$491: ESP320
U$47, U$104, U$142, U$192, U$242, U$292, U$342, U$392, U$442, U$492: THING1
U$48, U$105, U$143, U$193, U$243, U$293, U$343, U$393, U$443, U$493: PLUS2
U$51, U$52, U$56, U$75, U$146, U$147, U$196, U$197, U$246, U$247, U$296, U$297, U$346, U$347, U$396, U$397, U$446, U$447, U$496, U$497: GND1
U$53, U$54, U$106, U$107, U$148, U$149, U$198, U$199, U$248, U$249, U$298, U$299, U$348, U$349, U$398, U$399, U$448, U$449, U$498, U$499: NC0

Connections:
3.3V: C1.1, C2.1, C4.1, C5.1, C10.1, D5.VCC, J6.VCC, JP1.2, R2.2, U2.2, U3.5, U6.3V3, U7.4, U7.16
3.3V1: C9.1, C13.1, C14.1, C18.1, C20.1, D9.VCC, J7.VCC, JP2.2, R14.2, U9.5, U10.2, U11.3V3, U12.4, U12.16
3.3V2: C22.1, C25.1, C26.1, C29.1, C30.1, D15.VCC, J11.VCC, JP3.2, R27.2, U16.5, U17.2, U18.3V3, U19.4, U19.16
3.3V3: C32.1, C35.1, C36.1, C39.1, C40.1, D20.VCC, J15.VCC, JP4.2, R39.2, U23.5, U24.2, U25.3V3, U26.4, U26.16
3.3V4: C42.1, C45.1, C46.1, C49.1, C50.1, D25.VCC, J19.VCC, JP5.2, R50.2, U30.5, U31.2, U32.3V3, U33.4, U33.16
3.3V5: C52.1, C55.1, C56.1, C59.1, C60.1, D30.VCC, J23.VCC, JP6.2, R61.2, U37.5, U38.2, U39.3V3, U40.4, U40.16
3.3V6: C62.1, C65.1, C66.1, C69.1, C70.1, D35.VCC, J27.VCC, JP7.2, R72.2, U44.5, U45.2, U46.3V3, U47.4, U47.16
3.3V7: C72.1, C75.1, C76.1, C79.1, C80.1, D40.VCC, J31.VCC, JP8.2, R83.2, U51.5, U52.2, U53.3V3, U54.4, U54.16
3.3V8: C82.1, C85.1, C86.1, C89.1, C90.1, D45.VCC, J35.VCC, JP9.2, R94.2, U58.5, U59.2, U60.3V3, U61.4, U61.16
3.3V9: C92.1, C95.1, C96.1, C99.1, C100.1, D50.VCC, J39.VCC, JP10.2, R105.2, U65.5, U66.2, U67.3V3, U68.4, U68.16
!RESET!: Q2.3, R2.1, S4.3, S4.4, U2.3, U6.RST
!RESET!1: Q1.3, R14.1, S2.3, S2.4, U10.3, U11.RST
!RESET!2: Q5.3, R27.1, S6.3, S6.4, U17.3, U18.RST
!RESET!3: Q7.3, R39.1, S8.3, S8.4, U24.3, U25.RST
!RESET!4: Q9.3, R50.1, S10.3, S10.4, U31.3, U32.RST
!RESET!5: Q11.3, R61.1, S12.3, S12.4, U38.3, U39.RST
!RESET!6: Q13.3, R72.1, S14.3, S14.4, U45.3, U46.RST
!RESET!7: Q15.3, R83.1, S16.3, S16.4, U52.3, U53.RST
!RESET!8: Q17.3, R94.1, S18.3, S18.4, U59.3, U60.RST
!RESET!9: Q19.3, R105.1, S20.3, S20.4, U66.3, U67.RST
CH340-DTR: Q2.1, R17.1, U7.13
CH340-DTR1: Q1.1, R12.1, U12.13
CH340-DTR2: Q5.1, R25.1, U19.13
CH340-DTR3: Q7.1, R37.1, U26.13
CH340-DTR4: Q9.1, R48.1, U33.13
CH340-DTR5: Q11.1, R59.1, U40.13
CH340-DTR6: Q13.1, R70.1, U47.13
CH340-DTR7: Q15.1, R81.1, U54.13
CH340-DTR8: Q17.1, R92.1, U61.13
CH340-DTR9: Q19.1, R103.1, U68.13
CH340-RTS: Q2.4, R18.1, U7.14
CH340-RTS1: Q1.4, R13.1, U12.14
CH340-RTS2: Q5.4, R26.1, U19.14
CH340-RTS3: Q7.4, R38.1, U26.14
CH340-RTS4: Q9.4, R49.1, U33.14
CH340-RTS5: Q11.4, R60.1, U40.14
CH340-RTS6: Q13.4, R71.1, U47.14
CH340-RTS7: Q15.4, R82.1, U54.14
CH340-RTS8: Q17.4, R93.1, U61.14
CH340-RTS9: Q19.4, R104.1, U68.14
CH340-RX: U2.35, U7.3
CH340-RX1: U10.35, U12.3
CH340-RX2: U17.35, U19.3
CH340-RX3: U24.35, U26.3
CH340-RX4: U31.35, U33.3
CH340-RX5: U38.35, U40.3
CH340-RX6: U45.35, U47.3
CH340-RX7: U52.35, U54.3
CH340-RX8: U59.35, U61.3
CH340-RX9: U66.35, U68.3
CH340-TX: U2.34, U7.2
CH340-TX1: U10.34, U12.2
CH340-TX2: U17.34, U19.2
CH340-TX3: U24.34, U26.2
CH340-TX4: U31.34, U33.2
CH340-TX5: U38.34, U40.2
CH340-TX6: U45.34, U47.2
CH340-TX7: U52.34, U54.2
CH340-TX8: U59.34, U61.2
CH340-TX9: U66.34, U68.2
CHG: D1.C, U1.1
CHG1: D2.C, U8.1
CHG2: D10.C, U15.1
CHG3: D16.C, U22.1
CHG4: D21.C, U29.1
CHG5: D26.C, U36.1
CHG6: D31.C, U43.1
CHG7: D36.C, U50.1
CHG8: D41.C, U57.1
CHG9: D46.C, U64.1
CHG_LED: D1.A, R3.2
CHG_LED1: D2.A, R5.2
CHG_LED2: D10.A, R23.2
CHG_LED3: D16.A, R35.2
CHG_LED4: D21.A, R46.2
CHG_LED5: D26.A, R57.2
CHG_LED6: D31.A, R68.2
CHG_LED7: D36.A, R79.2
CHG_LED8: D41.A, R90.2
CHG_LED9: D46.A, R101.2
D+: J1.A6, J1.B6, U7.5
D+1: J5.A6, J5.B6, U12.5
D+2: J10.A6, J10.B6, U19.5
D+3: J14.A6, J14.B6, U26.5
D+4: J18.A6, J18.B6, U33.5
D+5: J22.A6, J22.B6, U40.5
D+6: J26.A6, J26.B6, U47.5
D+7: J30.A6, J30.B6, U54.5
D+8: J34.A6, J34.B6, U61.5
D+9: J38.A6, J38.B6, U68.5
D-: J1.A7, J1.B7, U7.6
D-1: J5.A7, J5.B7, U12.6
D-2: J10.A7, J10.B7, U19.6
D-3: J14.A7, J14.B7, U26.6
D-4: J18.A7, J18.B7, U33.6
D-5: J22.A7, J22.B7, U40.6
D-6: J26.A7, J26.B7, U47.6
D-7: J30.A7, J30.B7, U54.6
D-8: J34.A7, J34.B7, U61.6
D-9: J38.A7, J38.B7, U68.6
DTR-10K: Q2.5, R17.2
DTR-10K1: Q1.5, R12.2
DTR-10K2: Q5.5, R25.2
DTR-10K3: Q7.5, R37.2
DTR-10K4: Q9.5, R48.2
DTR-10K5: Q11.5, R59.2
DTR-10K6: Q13.5, R70.2
DTR-10K7: Q15.5, R81.2
DTR-10K8: Q17.5, R92.2
DTR-10K9: Q19.5, R103.2
ESP_0/QPWR: Q2.6, S3.3, S3.4, TP1.P$1, U2.25, U5.3
ESP_0/QPWR1: Q1.6, S1.3, S1.4, TP5.P$1, U10.25, U14.3
ESP_0/QPWR2: Q5.6, S5.3, S5.4, TP9.P$1, U17.25, U21.3
ESP_0/QPWR3: Q7.6, S7.3, S7.4, TP13.P$1, U24.25, U28.3
ESP_0/QPWR4: Q9.6, S9.3, S9.4, TP17.P$1, U31.25, U35.3
ESP_0/QPWR5: Q11.6, S11.3, S11.4, TP21.P$1, U38.25, U42.3
ESP_0/QPWR6: Q13.6, S13.3, S13.4, TP25.P$1, U45.25, U49.3
ESP_0/QPWR7: Q15.6, S15.3, S15.4, TP29.P$1, U52.25, U56.3
ESP_0/QPWR8: Q17.6, S17.3, S17.4, TP33.P$1, U59.25, U63.3
ESP_0/QPWR9: Q19.6, S19.3, S19.4, TP37.P$1, U66.25, U70.3
ESP_2/RGB_DI: D5.DI, TP3.P$1, U2.24
ESP_2/RGB_DI1: D9.DI, TP7.P$1, U10.24
ESP_2/RGB_DI2: D15.DI, TP11.P$1, U17.24
ESP_2/RGB_DI3: D20.DI, TP15.P$1, U24.24
ESP_2/RGB_DI4: D25.DI, TP19.P$1, U31.24
ESP_2/RGB_DI5: D30.DI, TP23.P$1, U38.24
ESP_2/RGB_DI6: D35.DI, TP27.P$1, U45.24
ESP_2/RGB_DI7: D40.DI, TP31.P$1, U52.24
ESP_2/RGB_DI8: D45.DI, TP35.P$1, U59.24
ESP_2/RGB_DI9: D50.DI, TP39.P$1, U66.24
ESP_4/TP_FB: U2.26, U6.FREEBIE
ESP_4/TP_FB1: U10.26, U11.FREEBIE
ESP_4/TP_FB2: U17.26, U18.FREEBIE
ESP_4/TP_FB3: U24.26, U25.FREEBIE
ESP_4/TP_FB4: U31.26, U32.FREEBIE
ESP_4/TP_FB5: U38.26, U39.FREEBIE
ESP_4/TP_FB6: U45.26, U46.FREEBIE
ESP_4/TP_FB7: U52.26, U53.FREEBIE
ESP_4/TP_FB8: U59.26, U60.FREEBIE
ESP_4/TP_FB9: U66.26, U67.FREEBIE
ESP_5/SD_CS: J6.CS/DAT3, TP4.P$1, U2.29
ESP_5/SD_CS1: J7.CS/DAT3, TP8.P$1, U10.29
ESP_5/SD_CS2: J11.CS/DAT3, TP12.P$1, U17.29
ESP_5/SD_CS3: J15.CS/DAT3, TP16.P$1, U24.29
ESP_5/SD_CS4: J19.CS/DAT3, TP20.P$1, U31.29
ESP_5/SD_CS5: J23.CS/DAT3, TP24.P$1, U38.29
ESP_5/SD_CS6: J27.CS/DAT3, TP28.P$1, U45.29
ESP_5/SD_CS7: J31.CS/DAT3, TP32.P$1, U52.29
ESP_5/SD_CS8: J35.CS/DAT3, TP36.P$1, U59.29
ESP_5/SD_CS9: J39.CS/DAT3, TP40.P$1, U66.29
ESP_12/TP_1: U10.14, U11.12
ESP_12/TP_2: U17.14, U18.12
ESP_12/TP_3: U24.14, U25.12
ESP_12/TP_4: U31.14, U32.12
ESP_12/TP_5: U38.14, U39.12
ESP_12/TP_6: U45.14, U46.12
ESP_12/TP_7: U52.14, U53.12
ESP_12/TP_8: U59.14, U60.12
ESP_12/TP_9: U66.14, U67.12
ESP_12/TP_12: U2.14, U6.12
ESP_13/TP_13/LED: R4.1, U2.16, U6.13
ESP_13/TP_13/LED1: R15.1, U10.16, U11.13
ESP_13/TP_13/LED2: R28.1, U17.16, U18.13
ESP_13/TP_13/LED3: R40.1, U24.16, U25.13
ESP_13/TP_13/LED4: R51.1, U31.16, U32.13
ESP_13/TP_13/LED5: R62.1, U38.16, U39.13
ESP_13/TP_13/LED6: R73.1, U45.16, U46.13
ESP_13/TP_13/LED7: R84.1, U52.16, U53.13
ESP_13/TP_13/LED8: R95.1, U59.16, U60.13
ESP_13/TP_13/LED9: R106.1, U66.16, U67.13
ESP_14/TP_1: U10.13, U11.7
ESP_14/TP_2: U17.13, U18.7
ESP_14/TP_3: U24.13, U25.7
ESP_14/TP_4: U31.13, U32.7
ESP_14/TP_5: U38.13, U39.7
ESP_14/TP_6: U45.13, U46.7
ESP_14/TP_7: U2.13, U6.7
ESP_14/TP_8: U52.13, U53.7
ESP_14/TP_9: U59.13, U60.7
ESP_14/TP_10: U66.13, U67.7
ESP_15/TP_1: U10.23, U11.9
ESP_15/TP_2: U17.23, U18.9
ESP_15/TP_3: U24.23, U25.9
ESP_15/TP_4: U31.23, U32.9
ESP_15/TP_5: U38.23, U39.9
ESP_15/TP_6: U45.23, U46.9
ESP_15/TP_7: U52.23, U53.9
ESP_15/TP_8: U59.23, U60.9
ESP_15/TP_9: U2.23, U6.9
ESP_15/TP_10: U66.23, U67.9
ESP_16/TP_RX: U2.27, U6.RX
ESP_16/TP_RX1: U10.27, U11.RX
ESP_16/TP_RX2: U17.27, U18.RX
ESP_16/TP_RX3: U24.27, U25.RX
ESP_16/TP_RX4: U31.27, U32.RX
ESP_16/TP_RX5: U38.27, U39.RX
ESP_16/TP_RX6: U45.27, U46.RX
ESP_16/TP_RX7: U52.27, U53.RX
ESP_16/TP_RX8: U59.27, U60.RX
ESP_16/TP_RX9: U66.27, U67.RX
ESP_17/TP_TX: U2.28, U6.TX
ESP_17/TP_TX1: U10.28, U11.TX
ESP_17/TP_TX2: U17.28, U18.TX
ESP_17/TP_TX3: U24.28, U25.TX
ESP_17/TP_TX4: U31.28, U32.TX
ESP_17/TP_TX5: U38.28, U39.TX
ESP_17/TP_TX6: U45.28, U46.TX
ESP_17/TP_TX7: U52.28, U53.TX
ESP_17/TP_TX8: U59.28, U60.TX
ESP_17/TP_TX9: U66.28, U67.TX
ESP_18/TP_SCK: J6.SCLK, U2.30, U6.SCK
ESP_18/TP_SCK1: J7.SCLK, U10.30, U11.SCK
ESP_18/TP_SCK2: J11.SCLK, U17.30, U18.SCK
ESP_18/TP_SCK3: J15.SCLK, U24.30, U25.SCK
ESP_18/TP_SCK4: J19.SCLK, U31.30, U32.SCK
ESP_18/TP_SCK5: J23.SCLK, U38.30, U39.SCK
ESP_18/TP_SCK6: J27.SCLK, U45.30, U46.SCK
ESP_18/TP_SCK7: J31.SCLK, U52.30, U53.SCK
ESP_18/TP_SCK8: J35.SCLK, U59.30, U60.SCK
ESP_18/TP_SCK9: J39.SCLK, U66.30, U67.SCK
ESP_19/TP_CIPO: J6.DO/DAT0, U2.31, U6.CIPO
ESP_19/TP_CIPO1: J7.DO/DAT0, U10.31, U11.CIPO
ESP_19/TP_CIPO2: J11.DO/DAT0, U17.31, U18.CIPO
ESP_19/TP_CIPO3: J15.DO/DAT0, U24.31, U25.CIPO
ESP_19/TP_CIPO4: J19.DO/DAT0, U31.31, U32.CIPO
ESP_19/TP_CIPO5: J23.DO/DAT0, U38.31, U39.CIPO
ESP_19/TP_CIPO6: J27.DO/DAT0, U45.31, U46.CIPO
ESP_19/TP_CIPO7: J31.DO/DAT0, U52.31, U53.CIPO
ESP_19/TP_CIPO8: J35.DO/DAT0, U59.31, U60.CIPO
ESP_19/TP_CIPO9: J39.DO/DAT0, U66.31, U67.CIPO
ESP_21/TP_SDA: J3.3, U2.33, U4.8, U6.SDA
ESP_21/TP_SDA1: J2.3, U10.33, U11.SDA, U13.8
ESP_21/TP_SDA2: J9.3, U17.33, U18.SDA, U20.8
ESP_21/TP_SDA3: J13.3, U24.33, U25.SDA, U27.8
ESP_21/TP_SDA4: J17.3, U31.33, U32.SDA, U34.8
ESP_21/TP_SDA5: J21.3, U38.33, U39.SDA, U41.8
ESP_21/TP_SDA6: J25.3, U45.33, U46.SDA, U48.8
ESP_21/TP_SDA7: J29.3, U52.33, U53.SDA, U55.8
ESP_21/TP_SDA8: J33.3, U59.33, U60.SDA, U62.8
ESP_21/TP_SDA9: J37.3, U66.33, U67.SDA, U69.8
ESP_22/TP_SCL: J3.4, U2.36, U4.7, U6.SCL
ESP_22/TP_SCL1: J2.4, U10.36, U11.SCL, U13.7
ESP_22/TP_SCL2: J9.4, U17.36, U18.SCL, U20.7
ESP_22/TP_SCL3: J13.4, U24.36, U25.SCL, U27.7
ESP_22/TP_SCL4: J17.4, U31.36, U32.SCL, U34.7
ESP_22/TP_SCL5: J21.4, U38.36, U39.SCL, U41.7
ESP_22/TP_SCL6: J25.4, U45.36, U46.SCL, U48.7
ESP_22/TP_SCL7: J29.4, U52.36, U53.SCL, U55.7
ESP_22/TP_SCL8: J33.4, U59.36, U60.SCL, U62.7
ESP_22/TP_SCL9: J37.4, U66.36, U67.SCL, U69.7
ESP_23/TP_COPI: J6.DI/CMD, U2.37, U6.COPI
ESP_23/TP_COPI1: J7.DI/CMD, U10.37, U11.COPI
ESP_23/TP_COPI2: J11.DI/CMD, U17.37, U18.COPI
ESP_23/TP_COPI3: J15.DI/CMD, U24.37, U25.COPI
ESP_23/TP_COPI4: J19.DI/CMD, U31.37, U32.COPI
ESP_23/TP_COPI5: J23.DI/CMD, U38.37, U39.COPI
ESP_23/TP_COPI6: J27.DI/CMD, U45.37, U46.COPI
ESP_23/TP_COPI7: J31.DI/CMD, U52.37, U53.COPI
ESP_23/TP_COPI8: J35.DI/CMD, U59.37, U60.COPI
ESP_23/TP_COPI9: J39.DI/CMD, U66.37, U67.COPI
ESP_25/TP_A1: U2.10, U6.A1
ESP_25/TP_A2: U10.10, U11.A1
ESP_25/TP_A3: U17.10, U18.A1
ESP_25/TP_A4: U24.10, U25.A1
ESP_25/TP_A5: U31.10, U32.A1
ESP_25/TP_A6: U38.10, U39.A1
ESP_25/TP_A7: U45.10, U46.A1
ESP_25/TP_A8: U52.10, U53.A1
ESP_25/TP_A9: U59.10, U60.A1
ESP_25/TP_A10: U66.10, U67.A1
ESP_26/TP_A0: U2.11, U6.A0
ESP_26/TP_A1: U10.11, U11.A0
ESP_26/TP_A2: U17.11, U18.A0
ESP_26/TP_A3: U24.11, U25.A0
ESP_26/TP_A4: U31.11, U32.A0
ESP_26/TP_A5: U38.11, U39.A0
ESP_26/TP_A6: U45.11, U46.A0
ESP_26/TP_A7: U52.11, U53.A0
ESP_26/TP_A8: U59.11, U60.A0
ESP_26/TP_A9: U66.11, U67.A0
ESP_27/TP_1: U10.12, U11.11
ESP_27/TP_2: U17.12, U18.11
ESP_27/TP_3: U24.12, U25.11
ESP_27/TP_4: U31.12, U32.11
ESP_27/TP_5: U38.12, U39.11
ESP_27/TP_6: U45.12, U46.11
ESP_27/TP_7: U52.12, U53.11
ESP_27/TP_8: U59.12, U60.11
ESP_27/TP_9: U66.12, U67.11
ESP_27/TP_11: U2.12, U6.11
ESP_32/TP_1: U10.8, U11.8
ESP_32/TP_2: U17.8, U18.8
ESP_32/TP_3: U24.8, U25.8
ESP_32/TP_4: U31.8, U32.8
ESP_32/TP_5: U38.8, U39.8
ESP_32/TP_6: U45.8, U46.8
ESP_32/TP_7: U52.8, U53.8
ESP_32/TP_8: U2.8, U6.8
ESP_32/TP_9: U59.8, U60.8
ESP_32/TP_10: U66.8, U67.8
ESP_33/TP_1: U10.9, U11.10
ESP_33/TP_2: U17.9, U18.10
ESP_33/TP_3: U24.9, U25.10
ESP_33/TP_4: U31.9, U32.10
ESP_33/TP_5: U38.9, U39.10
ESP_33/TP_6: U45.9, U46.10
ESP_33/TP_7: U52.9, U53.10
ESP_33/TP_8: U59.9, U60.10
ESP_33/TP_9: U66.9, U67.10
ESP_33/TP_10: U2.9, U6.10
ESP_34/TP_A1: U10.6, U11.A2
ESP_34/TP_A2: U2.6, U6.A2
ESP_34/TP_A3: U17.6, U18.A2
ESP_34/TP_A4: U24.6, U25.A2
ESP_34/TP_A5: U31.6, U32.A2
ESP_34/TP_A6: U38.6, U39.A2
ESP_34/TP_A7: U45.6, U46.A2
ESP_34/TP_A8: U52.6, U53.A2
ESP_34/TP_A9: U59.6, U60.A2
ESP_34/TP_A10: U66.6, U67.A2
ESP_35/TP_A1: U10.7, U11.A5
ESP_35/TP_A2: U17.7, U18.A5
ESP_35/TP_A3: U24.7, U25.A5
ESP_35/TP_A4: U31.7, U32.A5
ESP_35/TP_A5: U2.7, U6.A5
ESP_35/TP_A6: U38.7, U39.A5
ESP_35/TP_A7: U45.7, U46.A5
ESP_35/TP_A8: U52.7, U53.A5
ESP_35/TP_A9: U59.7, U60.A5
ESP_35/TP_A10: U66.7, U67.A5
ESP_36/TP_A1: U10.4, U11.A4
ESP_36/TP_A2: U17.4, U18.A4
ESP_36/TP_A3: U24.4, U25.A4
ESP_36/TP_A4: U2.4, U6.A4
ESP_36/TP_A5: U31.4, U32.A4
ESP_36/TP_A6: U38.4, U39.A4
ESP_36/TP_A7: U45.4, U46.A4
ESP_36/TP_A8: U52.4, U53.A4
ESP_36/TP_A9: U59.4, U60.A4
ESP_36/TP_A10: U66.4, U67.A4
ESP_39/TP_A1: U10.5, U11.A3
ESP_39/TP_A2: U17.5, U18.A3
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

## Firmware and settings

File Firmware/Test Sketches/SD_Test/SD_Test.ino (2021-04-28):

/*
  Written for ESP32
  Just test to see if we can read/write to an SD card over SPI

  Be sure to set the CS pin correctly at top of code below

  Common:
  1048576 bytes read for 3268 ms
  1048576 bytes written for 6269 ms
*/
#include "FS.h"
#include "SD.h"
#include "SPI.h"

const int sd_cs = 5; //Thing Plus C

void listDir(fs::FS &fs, const char * dirname, uint8_t levels) {
  Serial.printf("Listing directory: %s\n", dirname);

  File root = fs.open(dirname);
  if (!root) {
    Serial.println("Failed to open directory");
    return;
  }
  if (!root.isDirectory()) {
    Serial.println("Not a directory");
    return;
  }

  File file = root.openNextFile();
  while (file) {
    if (file.isDirectory()) {
      Serial.print("  DIR : ");
      Serial.println(file.name());
      if (levels) {
        listDir(fs, file.name(), levels - 1);
      }
    } else {
      Serial.print("  FILE: ");
      Serial.print(file.name());
      Serial.print("  SIZE: ");
      Serial.println(file.size());
    }
    file = root.openNextFile();
  }
}

void createDir(fs::FS &fs, const char * path) {
  Serial.printf("Creating Dir: %s\n", path);
  if (fs.mkdir(path)) {
    Serial.println("Dir created");
  } else {
    Serial.println("mkdir failed");
  }
}

void removeDir(fs::FS &fs, const char * path) {
  Serial.printf("Removing Dir: %s\n", path);
  if (fs.rmdir(path)) {
    Serial.println("Dir removed");
  } else {
    Serial.println("rmdir failed");
  }
}

void readFile(fs::FS &fs, const char * path) {
  Serial.printf("Reading file: %s\n", path);

  File file = fs.open(path);
  if (!file) {
    Serial.println("Failed to open file for reading");
    return;
  }

  Serial.print("Read from file: ");
  while (file.available()) {
    Serial.write(file.read());
  }
  file.close();
}

void writeFile(fs::FS &fs, const char * path, const char * message) {
  Serial.printf("Writing file: %s\n", path);

  File file = fs.open(path, FILE_WRITE);
  if (!file) {
    Serial.println("Failed to open file for writing");
    return;
  }
  if (file.print(message)) {
    Serial.println("File written");
  } else {
    Serial.println("Write failed");
  }
  file.close();
}

void appendFile(fs::FS &fs, const char * path, const char * message) {
  Serial.printf("Appending to file: %s\n", path);

  File file = fs.open(path, FILE_APPEND);
  if (!file) {
    Serial.println("Failed to open file for appending");
    return;
  }
  if (file.print(message)) {
    Serial.println("Message appended");
  } else {
    Serial.println("Append failed");
  }
  file.close();
}

void renameFile(fs::FS &fs, const char * path1, const char * path2) {
  Serial.printf("Renaming file %s to %s\n", path1, path2);
  if (fs.rename(path1, path2)) {
    Serial.println("File renamed");
  } else {
    Serial.println("Rename failed");
  }
}

void deleteFile(fs::FS &fs, const char * path) {
  Serial.printf("Deleting file: %s\n", path);
  if (fs.remove(path)) {
    Serial.println("File deleted");
  } else {
    Serial.println("Delete failed");
  }
}

void testFileIO(fs::FS &fs, const char * path) {
  File file = fs.open(path);
  static uint8_t buf[512];
  size_t len = 0;
  uint32_t start = millis();
  uint32_t end = start;
  if (file) {
    len = file.size();
    size_t flen = len;
    start = millis();
    while (len) {
      size_t toRead = len;
      if (toRead > 512) {
        toRead = 512;
      }
      file.read(buf, toRead);
      len -= toRead;
    }
    end = millis() - start;
    Serial.printf("%u bytes read for %u ms\n", flen, end);
    file.close();
  } else {
    Serial.println("Failed to open file for reading");
  }


  file = fs.open(path, FILE_WRITE);
  if (!file) {
    Serial.println("Failed to open file for writing");
    return;
  }

  size_t i;
  start = millis();
  for (i = 0; i < 2048; i++) {
    file.write(buf, 512);
  }
  end = millis() - start;
  Serial.printf("%u bytes written for %u ms\n", 2048 * 512, end);
  file.close();
}


void setup() {
  Serial.begin(115200);
  delay(1000);
  Serial.println("SD test");

  if (!SD.begin(sd_cs)) {
    Serial.println("Card Mount Failed");
    return;
  }
  uint8_t cardType = SD.cardType();

  if (cardType == CARD_NONE) {
    Serial.println("No SD card attached");
    return;
  }

  Serial.print("SD Card Type: ");
  if (cardType == CARD_MMC) {
    Serial.println("MMC");
  } else if (cardType == CARD_SD) {
    Serial.println("SDSC");
  } else if (cardType == CARD_SDHC) {
    Serial.println("SDHC");
  } else {
    Serial.println("UNKNOWN");
  }

  uint64_t cardSize = SD.cardSize() / (1024 * 1024);
  Serial.printf("SD Card Size: %lluMB\n", cardSize);

  listDir(SD, "/", 0);
  createDir(SD, "/mydir");
  listDir(SD, "/", 0);
  removeDir(SD, "/mydir");
  listDir(SD, "/", 2);
  writeFile(SD, "/hello.txt", "Hello ");
  appendFile(SD, "/hello.txt", "World!\n");
  readFile(SD, "/hello.txt");
  deleteFile(SD, "/foo.txt");
  renameFile(SD, "/hello.txt", "/foo.txt");
  readFile(SD, "/foo.txt");
  testFileIO(SD, "/test.txt");
  Serial.printf("Total space: %lluMB\n", SD.totalBytes() / (1024 * 1024));
  Serial.printf("Used space: %lluMB\n", SD.usedBytes() / (1024 * 1024));
}

void loop() {

}

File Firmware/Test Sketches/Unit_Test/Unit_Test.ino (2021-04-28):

/*
  Test:
  WS2812 all three RGB dies
  Fuel Gauge existance
  SD interface
  Stat LED
*/

const int statLED = 13;

//RGB LED
//=-=-=-=-=-=-=-=-=-=-=-=-=-=-=-=-=-=-=-=-=-=-=-=-=-=-=-=-=-=-=-=-=-=-=-=-=-=-=-=-=-=-=-=-=
#include <FastLED.h>

#define LED_PIN     2 //Pin 2 on Thing Plus C is connected to WS2812 LED
#define COLOR_ORDER GRB
#define CHIPSET     WS2812
#define NUM_LEDS    1

#define BRIGHTNESS  25

CRGB leds[NUM_LEDS];
//=-=-=-=-=-=-=-=-=-=-=-=-=-=-=-=-=-=-=-=-=-=-=-=-=-=-=-=-=-=-=-=-=-=-=-=-=-=-=-=-=-=-=-=-=

//Fuel gauge
//=-=-=-=-=-=-=-=-=-=-=-=-=-=-=-=-=-=-=-=-=-=-=-=-=-=-=-=-=-=-=-=-=-=-=-=-=-=-=-=-=-=-=-=-=
#include <SparkFun_MAX1704x_Fuel_Gauge_Arduino_Library.h> // Click here to get the library: http://librarymanager/All#SparkFun_MAX1704x_Fuel_Gauge_Arduino_Library
SFE_MAX1704X lipo(MAX1704X_MAX17048); // Allow access to all the 17048 features
//=-=-=-=-=-=-=-=-=-=-=-=-=-=-=-=-=-=-=-=-=-=-=-=-=-=-=-=-=-=-=-=-=-=-=-=-=-=-=-=-=-=-=-=-=

//SD Interface
//=-=-=-=-=-=-=-=-=-=-=-=-=-=-=-=-=-=-=-=-=-=-=-=-=-=-=-=-=-=-=-=-=-=-=-=-=-=-=-=-=-=-=-=-=
#include "FS.h"
#include "SD.h"
#include "SPI.h"

const int sd_cs = 5; //CS pin for Thing Plus C
//=-=-=-=-=-=-=-=-=-=-=-=-=-=-=-=-=-=-=-=-=-=-=-=-=-=-=-=-=-=-=-=-=-=-=-=-=-=-=-=-=-=-=-=-=

//EEPROM for storing settings
//-=-=-=-=-=-=-=-=-=-=-=-=-=-=-=-=-=-=-=-=-=-=-=-=-=-=-=-=-=-=-=-=-
#include <EEPROM.h>
#define EEPROM_SIZE 2048 //ESP32 emulates EEPROM in non-volatile storage (external flash IC). Max is 508k.
//-=-=-=-=-=-=-=-=-=-=-=-=-=-=-=-=-=-=-=-=-=-=-=-=-=-=-=-=-=-=-=-=-

//Global vars
//-=-=-=-=-=-=-=-=-=-=-=-=-=-=-=-=-=-=-=-=-=-=-=-=-=-=-=-=-=-=-=-=-
bool batteryGood = false;
bool sdGood = false;
//-=-=-=-=-=-=-=-=-=-=-=-=-=-=-=-=-=-=-=-=-=-=-=-=-=-=-=-=-=-=-=-=-

void setup()
{
  Serial.begin(115200);
  //delay(500);
  Serial.println("ESP32 Thing Plus Test");

  //  while (Serial.available()) Serial.read();
  //  delay(100);
  //  Serial.println("Press key to start");
  //  while (Serial.available() == 0) delay(10);

  Wire.begin();

  FastLED.addLeds<CHIPSET, LED_PIN, COLOR_ORDER>(leds, NUM_LEDS).setCorrection(TypicalLEDStrip);
  FastLED.setBrightness( BRIGHTNESS );

  pinMode(statLED, OUTPUT);

  //Check to see if EEPROM is blank
  if (EEPROM.begin(EEPROM_SIZE) == false)
    Serial.println(F("Failed to initialize EEPROM"));
  uint32_t testRead = 0;
  EEPROM.get(0, testRead);
  if (testRead == 0xFFFFFFFF)
  {
    Serial.println(F("EEPROM is blank. Running test"));

    testSD();

    testBattery();

    if (batteryGood == false)// || sdGood == false) //Don't make the sd test required
    {
      //Display red
      leds[0] = CRGB::Red;
      FastLED.show();
      while (1);
    }
    else
    {
      //Mark EEPROM as all good
      uint8_t myVal = 0xAA;
      EEPROM.put(0, myVal);
      EEPROM.commit();
    }
  }
}

void loop()
{
  //Loop LED display
  digitalWrite(statLED, !digitalRead(statLED));

  leds[0] = CRGB::Red;
  FastLED.show();
  delay(200);

  leds[0] = CRGB::Green;
  FastLED.show();
  delay(200);

  leds[0] = CRGB::Blue;
  FastLED.show();
  delay(200);

  leds[0] = CRGB::Black;
  FastLED.show();
  delay(100);

  leds[0] = CRGB::White;
  FastLED.show();
  delay(1000);

  leds[0] = CRGB::Black;
  FastLED.show();
  delay(100);
}

void testBattery()
{
  // Set up the MAX17048 LiPo fuel gauge:
  if (lipo.begin() == false) // Connect to the MAX17048 using the default wire port
  {
    Serial.println(F("MAX17048 BAD"));
    return;
  }

  Serial.println("Fuel gauge detected");
  batteryGood = true;
}

void testSD()
{
  if (!SD.begin(sd_cs)) {
    Serial.println("Card Mount Failed");
    return;
  }
  uint8_t cardType = SD.cardType();

  if (cardType == CARD_NONE) {
    Serial.println("No SD card attached");
    return;
  }

  Serial.print("SD Card Type: ");
  if (cardType == CARD_MMC) {
    Serial.print("MMC");
  } else if (cardType == CARD_SD) {
    Serial.print("SDSC");
  } else if (cardType == CARD_SDHC) {
    Serial.print("SDHC");
  } else {
    Serial.print("UNKNOWN");
  }

  uint64_t cardSize = SD.cardSize() / (1024 * 1024);
  Serial.printf(" %lluMB ", cardSize);

  Serial.print("SD Good");

  Serial.println();

  sdGood = true;
}

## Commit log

2021-02-16 Add production files
    [ESP32_Thing_Plus-Panel.GBL, ESP32_Thing_Plus-Panel.GBO, ESP32_Thing_Plus-Panel.GBP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]
2021-04-28 Add test sketches
    [ESP32_Thing_Plus.brd, ESP32_Thing_Plus.sch]
2021-05-10 Update file names
    [SparkFun ESP32 Thing Plus C.brd, SparkFun ESP32 Thing Plus C.sch]

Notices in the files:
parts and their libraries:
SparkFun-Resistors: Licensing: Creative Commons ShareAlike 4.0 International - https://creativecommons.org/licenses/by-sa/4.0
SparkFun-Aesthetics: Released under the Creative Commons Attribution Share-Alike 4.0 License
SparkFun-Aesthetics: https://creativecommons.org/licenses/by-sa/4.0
